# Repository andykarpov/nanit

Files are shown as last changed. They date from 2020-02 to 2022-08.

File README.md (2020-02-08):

# Alternative PCB for NANIT radiation counter.

The original article: https://radiokot.ru/circuit/digital/measure/117/

## Changes to the original schematics:

- Added factory manufactured SMD transformer instead of hand-made coil
- Added LED driver for display backlight

## PCB renders:

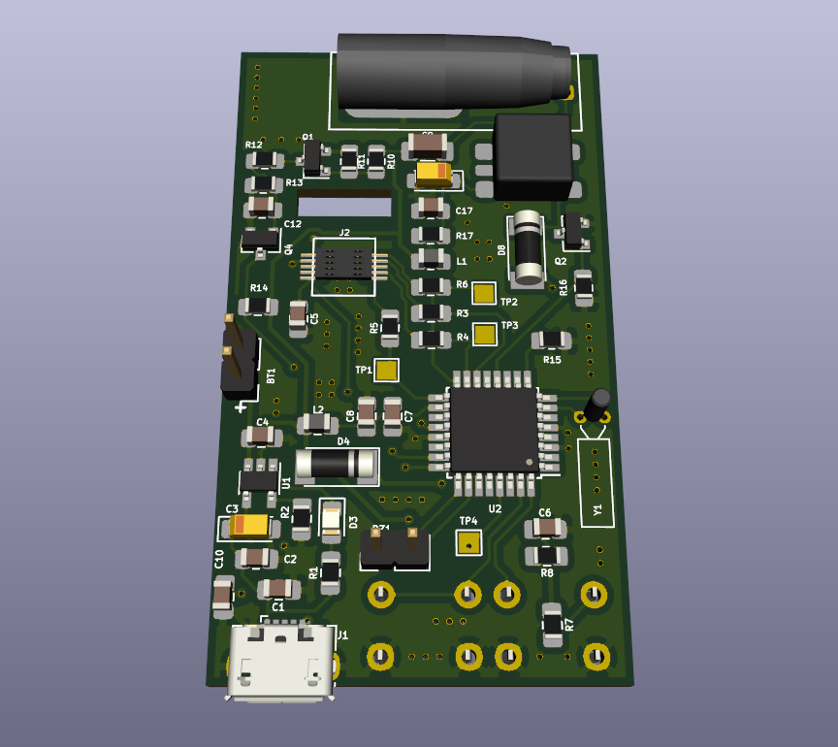
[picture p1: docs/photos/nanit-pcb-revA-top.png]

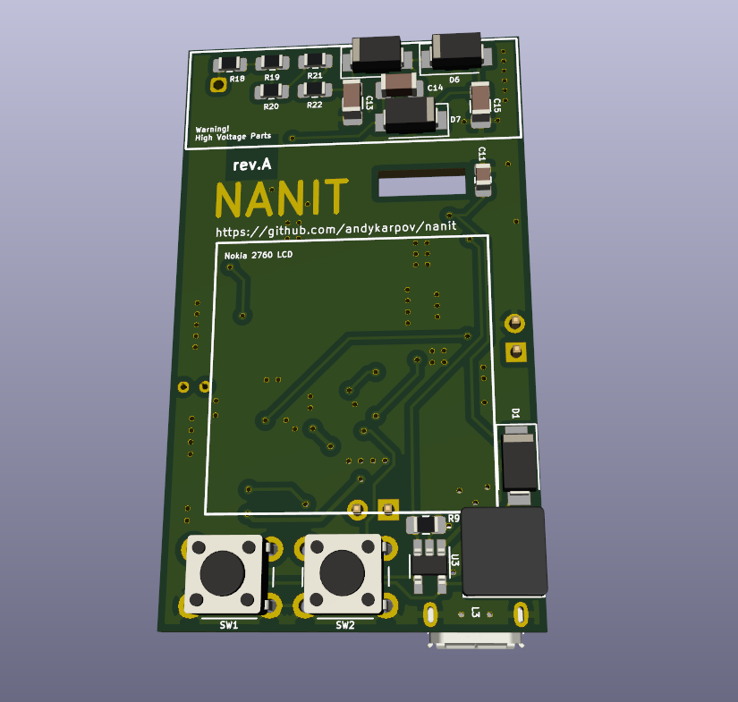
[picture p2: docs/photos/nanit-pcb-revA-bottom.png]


## OSHPark project link:

https://oshpark.com/shared_projects/OVV7hNvF

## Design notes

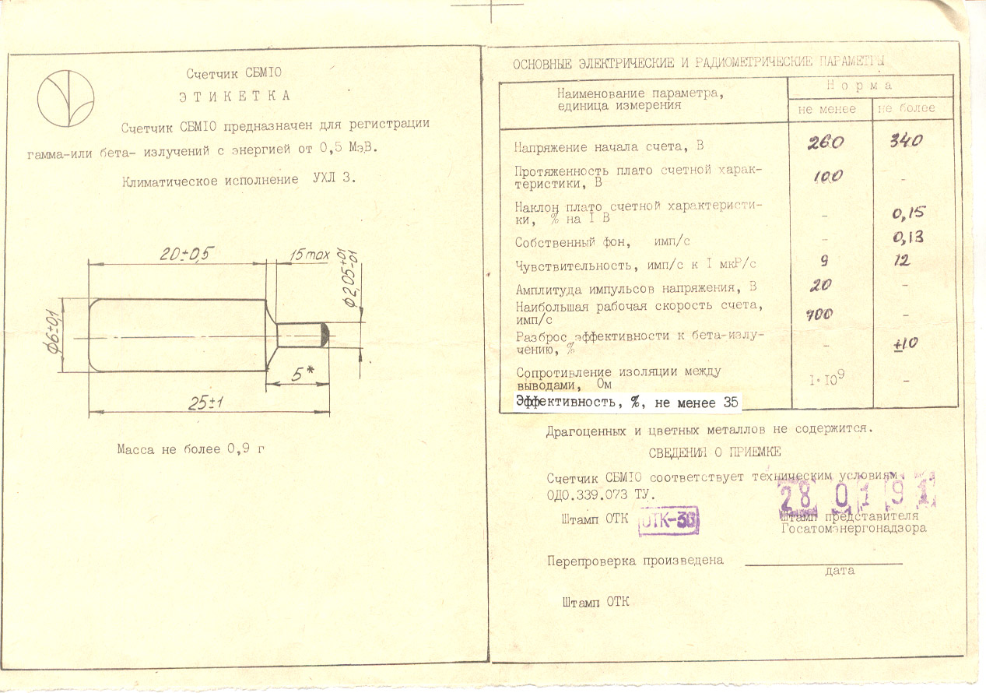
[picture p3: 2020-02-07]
docs/datasheets/sbm10.jpg

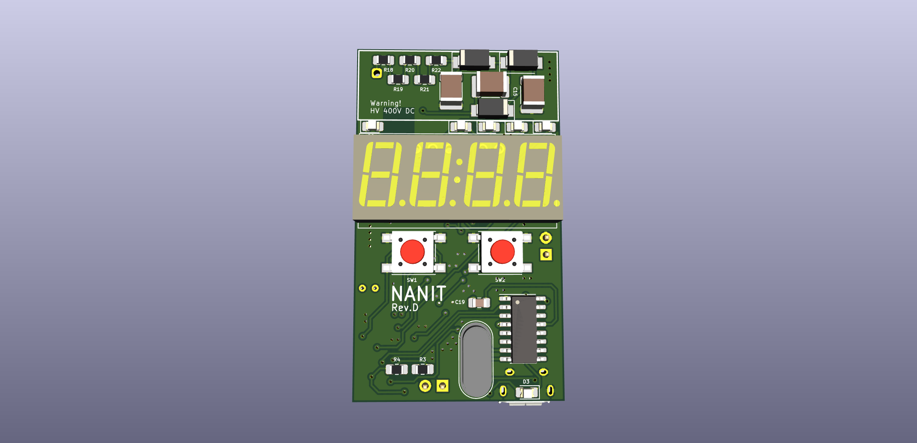
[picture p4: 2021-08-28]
docs/photos/nanit-revD-top.png

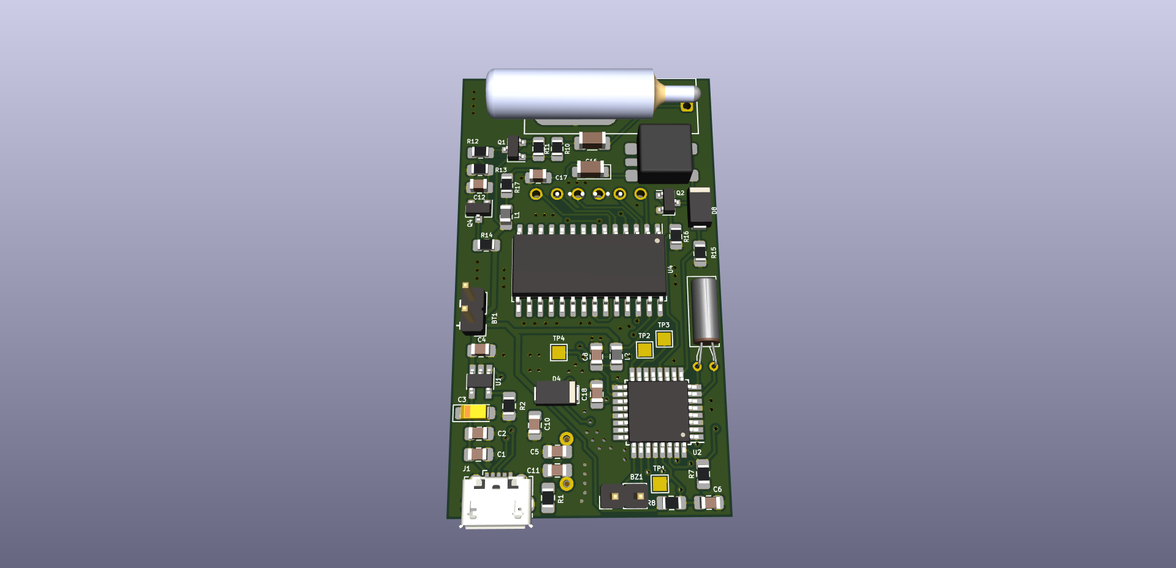
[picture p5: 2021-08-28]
docs/photos/nanit-revD-bottom.png

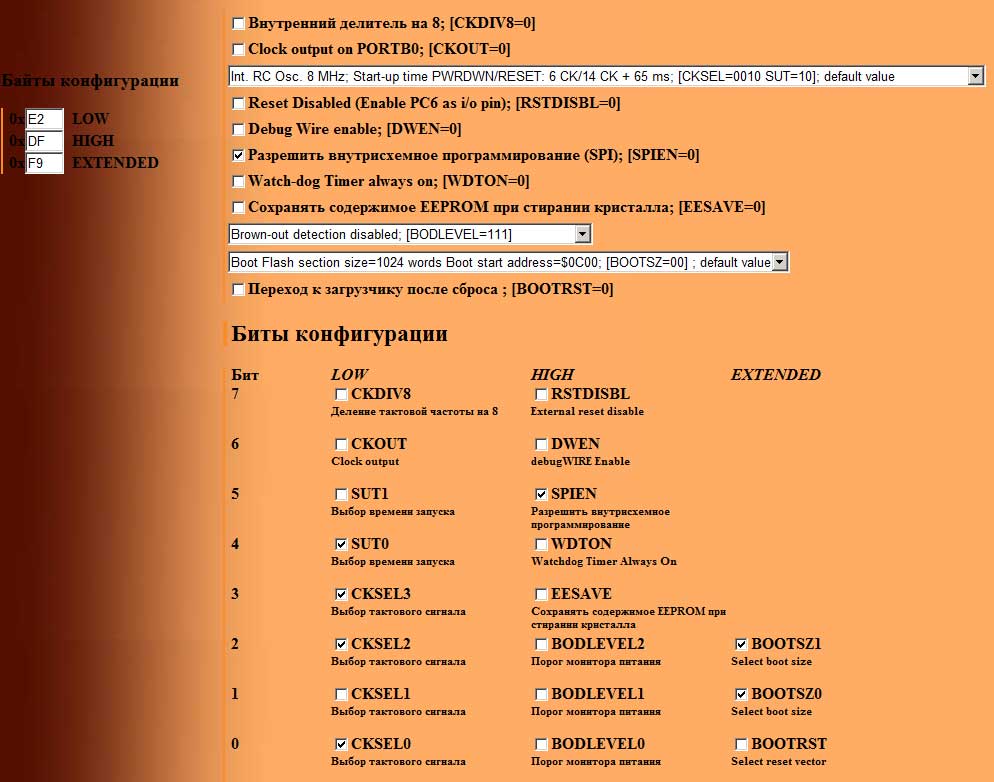
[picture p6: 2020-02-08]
firmware/sbm21/fuses.jpg

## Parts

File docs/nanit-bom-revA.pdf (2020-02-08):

### nanit-revA-bom.csv

### Page 1

Qty | Reference(s) | Value | Package | Comments
1 | BT1 | 3.7V li-ion battery | 3.7v 250mAh li-ion battery with protection
1 | BZ1 | Piezo Buzzer | 15mm piezo buzzer | voron.ua
7 | C1, C4, C5, C6, C7, C8, C17 | 100nF | 0805
2 | C2, C10 | 1uF | 0805
1 | C3 | 10uF | Tantalum A
1 | C9 | 10pF 1000V (C17UL100J-7ZN-X1T) | 1206 | voron.ua
1 | C11 | 22nF | 0805
1 | C12 | 220pF | 0805
3 | C13, C14, C15 | 100nF 600V | 1206 | voron.ua
1 | C16 | 47uF | Tantalum A
1 | D1 | SS14 | SMA
1 | D3 | LED | 0805
1 | D4 | 1N4148 | MELF
3 | D5, D6, D7 | US1M | SMA | voron.ua
1 | D8 | 18v (BZV55C18) | MELF | voron.ua
1 | J1 | USB_B_Micro | Micro USB
1 | J2 | DF23C-10DS-0.5V(51) | DF23C-10DS-0.5V(51) | https://prom.ua/p955569626-konnektor-displeya-dlya.html
2 | L1, L2 | 10uH | 0805
1 | L3 | 22uH | Coil
1 | Q1 | BC857 | SOT-23
1 | Q2 | IRLML6344 | SOT-23
1 | Q4 | BC847 | SOT-23
1 | R1 | 300R | 0805
1 | R2 | 2k* | 0805
4 | R3, R4, R5, R6 | 4k7 | 0805
6 | R7, R8, R11, R12, R13, R14 | 10k | 0805
1 | R9 | 6.34 | 0805
1 | R10 | 1k5 | 0805
1 | R15 | 750R | 0805
4 | R16, R18, R19, R20 | 1M | 0805
1 | R17 | 20R | 0805
2 | R21, R22 | 2M | 0805
1 | S1 | SBM-10 (SMB-21) | SBM-10 or SMB-21 geiger counter tube | https://www.olx.ua/obyavlenie/schetchik-sbm-10-IDGKPt7.html
2 | SW1, SW2 | Tact button | 6mm tact button

### nanit-revA-bom.csv

### Page 2

1 | TR1 | CEEH54 | CEEH54 | https://aliexpress.ru/item/32234817529.html
1 | U1 | LTC4054ES5-4.2 | SOT-23-5
1 | U2 | ATmega88PA-AU | TQFP-32 | voron.ua
1 | U3 | LT1937 | SOT-23-5 | https://aliexpress.ru/item/33025370052.html
1 | Y1 | 32.768 KHz | Crystal D2.1mm
1 | E1 | Enclosure | Sanhe 20-23-2
1 | DISP1 | Nokia 2660/2760 24x24mm display | Nokia 2660/2760 24x24mm display | https://himobile.kiev.ua/p61933946-displej-ekran-nokia.html

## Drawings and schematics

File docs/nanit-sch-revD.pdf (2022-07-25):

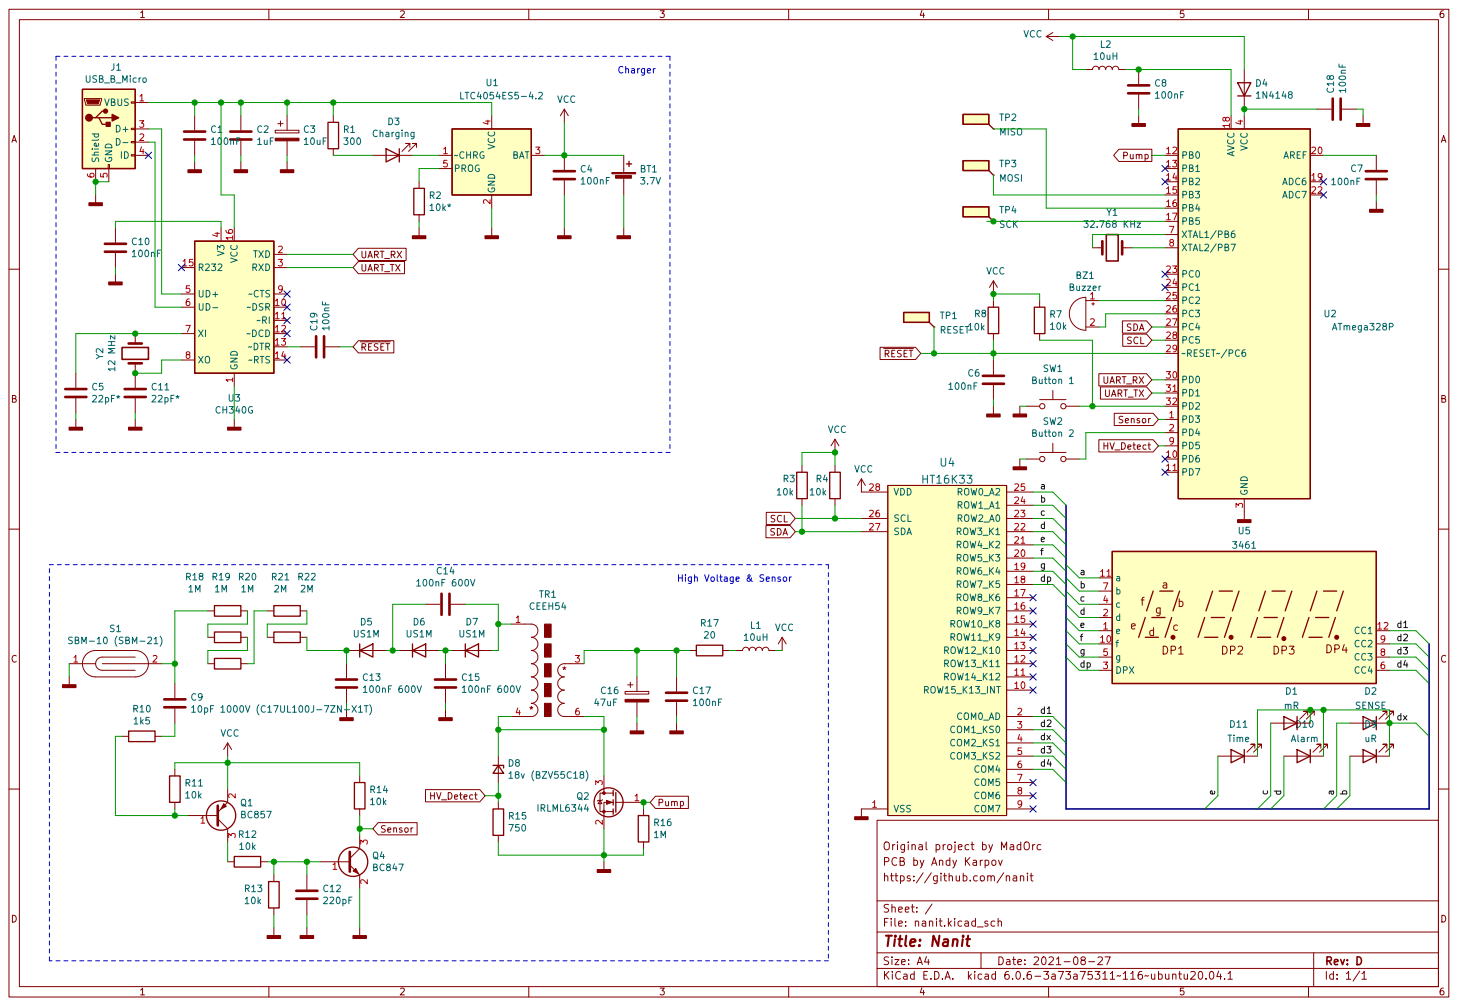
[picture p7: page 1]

4 UD+ 5 UD- 6 XI 7 XO 8 ~CTS9 U3 CH340G

fe High Voltage & Sensor

PCB by Andy Karpov
File: nanit.kicad_sch Sheet: / https://github.com/nanit

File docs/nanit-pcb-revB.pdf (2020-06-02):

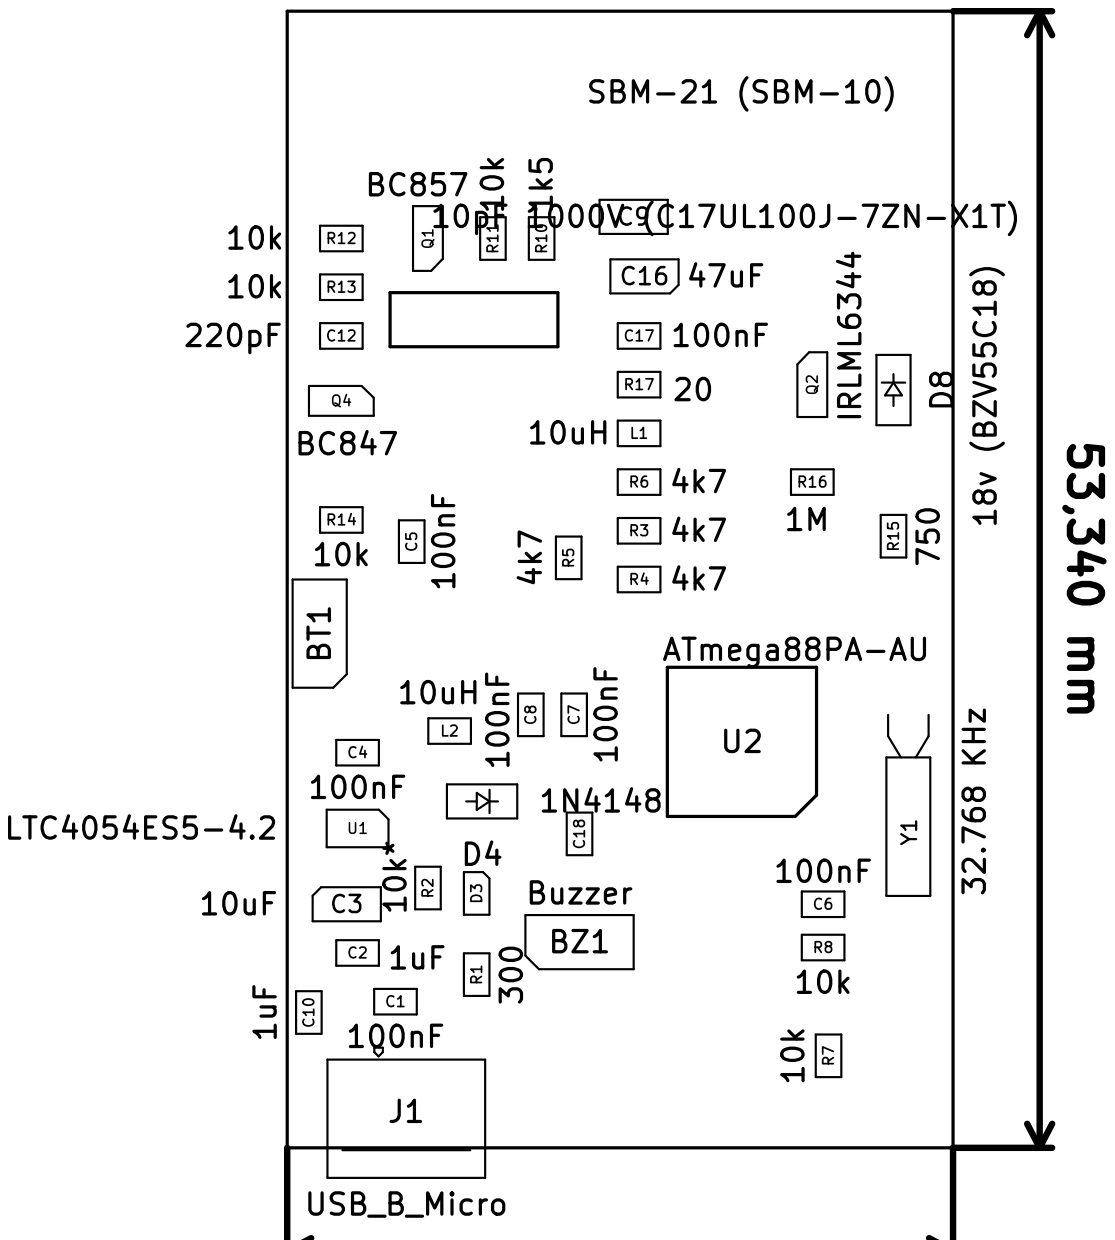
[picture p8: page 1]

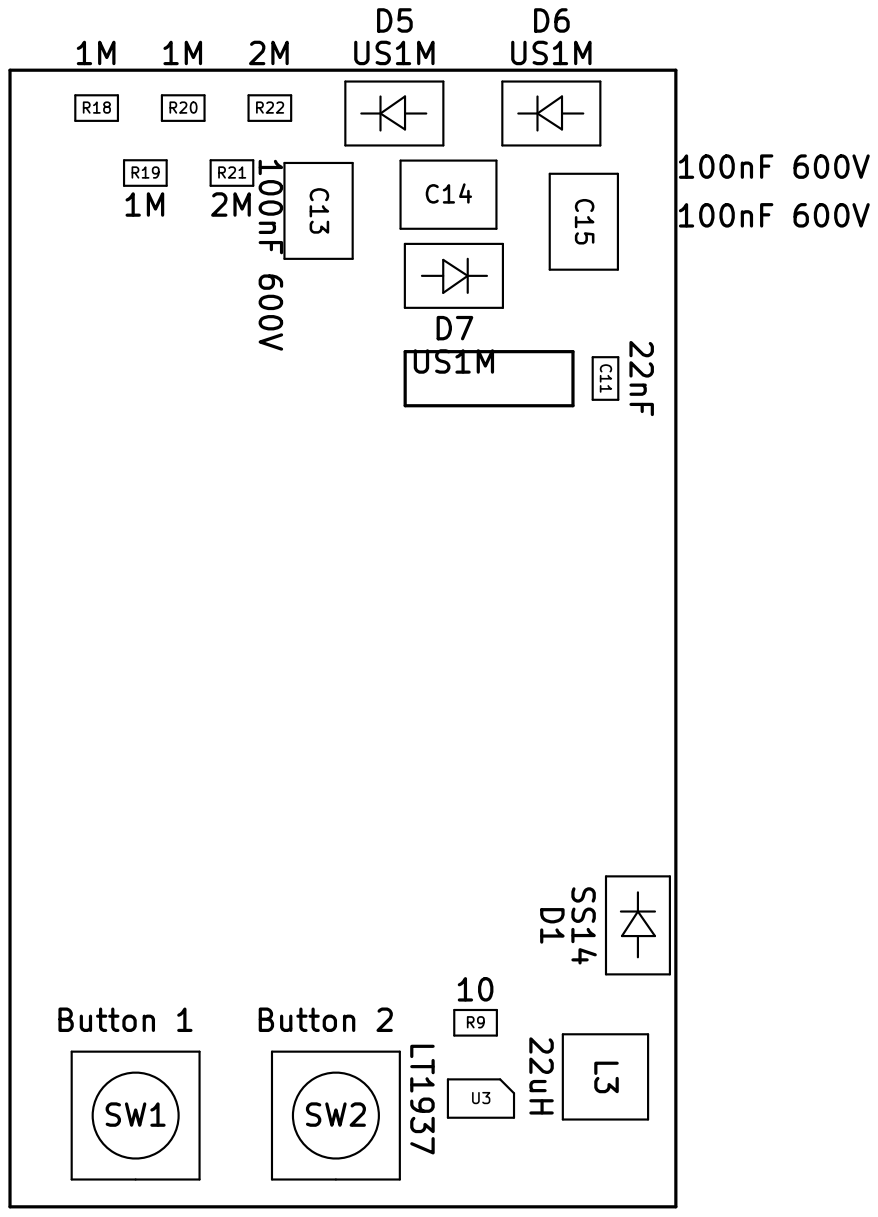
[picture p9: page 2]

### nanit-revA-bom.csv

### Page 1

Qty | Reference(s) | Value | Package | Comments
1 | BT1 | 3.7V li-ion battery | 3.7v 250mAh li-ion battery with protection
1 | BZ1 | Piezo Buzzer | 15mm piezo buzzer | voron.ua
7 | C1, C4, C5, C6, C7, C8, C17 | 100nF | 0805
2 | C2, C10 | 1uF | 0805
1 | C3 | 10uF | Tantalum A
1 | C9 | 10pF 1000V (C17UL100J-7ZN-X1T) | 1206 | voron.ua
1 | C11 | 22nF | 0805
1 | C12 | 220pF | 0805
3 | C13, C14, C15 | 100nF 600V | 1206 | voron.ua
1 | C16 | 47uF | Tantalum A
1 | D1 | SS14 | SMA
1 | D3 | LED | 0805
1 | D4 | 1N4148 | MELF
3 | D5, D6, D7 | US1M | SMA | voron.ua
1 | D8 | 18v (BZV55C18) | MELF | voron.ua
1 | J1 | USB_B_Micro | Micro USB
1 | J2 | DF23C-10DS-0.5V(51) | DF23C-10DS-0.5V(51) | https://prom.ua/p955569626-konnektor-displeya-dlya.html
2 | L1, L2 | 10uH | 0805
1 | L3 | 22uH | Coil
1 | Q1 | BC857 | SOT-23
1 | Q2 | IRLML6344 | SOT-23
1 | Q4 | BC847 | SOT-23
1 | R1 | 300R | 0805
1 | R2 | 2k* | 0805
4 | R3, R4, R5, R6 | 4k7 | 0805
6 | R7, R8, R11, R12, R13, R14 | 10k | 0805
1 | R9 | 6.34 | 0805
1 | R10 | 1k5 | 0805
1 | R15 | 750R | 0805
4 | R16, R18, R19, R20 | 1M | 0805
1 | R17 | 20R | 0805
2 | R21, R22 | 2M | 0805
1 | S1 | SBM-10 (SMB-21) | SBM-10 or SMB-21 geiger counter tube | https://www.olx.ua/obyavlenie/schetchik-sbm-10-IDGKPt7.html
2 | SW1, SW2 | Tact button | 6mm tact button

### nanit-revA-bom.csv

### Page 2

1 | TR1 | CEEH54 | CEEH54 | https://aliexpress.ru/item/32234817529.html
1 | U1 | LTC4054ES5-4.2 | SOT-23-5
1 | U2 | ATmega88PA-AU | TQFP-32 | voron.ua
1 | U3 | LT1937 | SOT-23-5 | https://aliexpress.ru/item/33025370052.html
1 | Y1 | 32.768 KHz | Crystal D2.1mm
1 | E1 | Enclosure | Sanhe 20-23-2
1 | DISP1 | Nokia 2660/2760 24x24mm display | Nokia 2660/2760 24x24mm display | https://himobile.kiev.ua/p61933946-displej-ekran-nokia.html



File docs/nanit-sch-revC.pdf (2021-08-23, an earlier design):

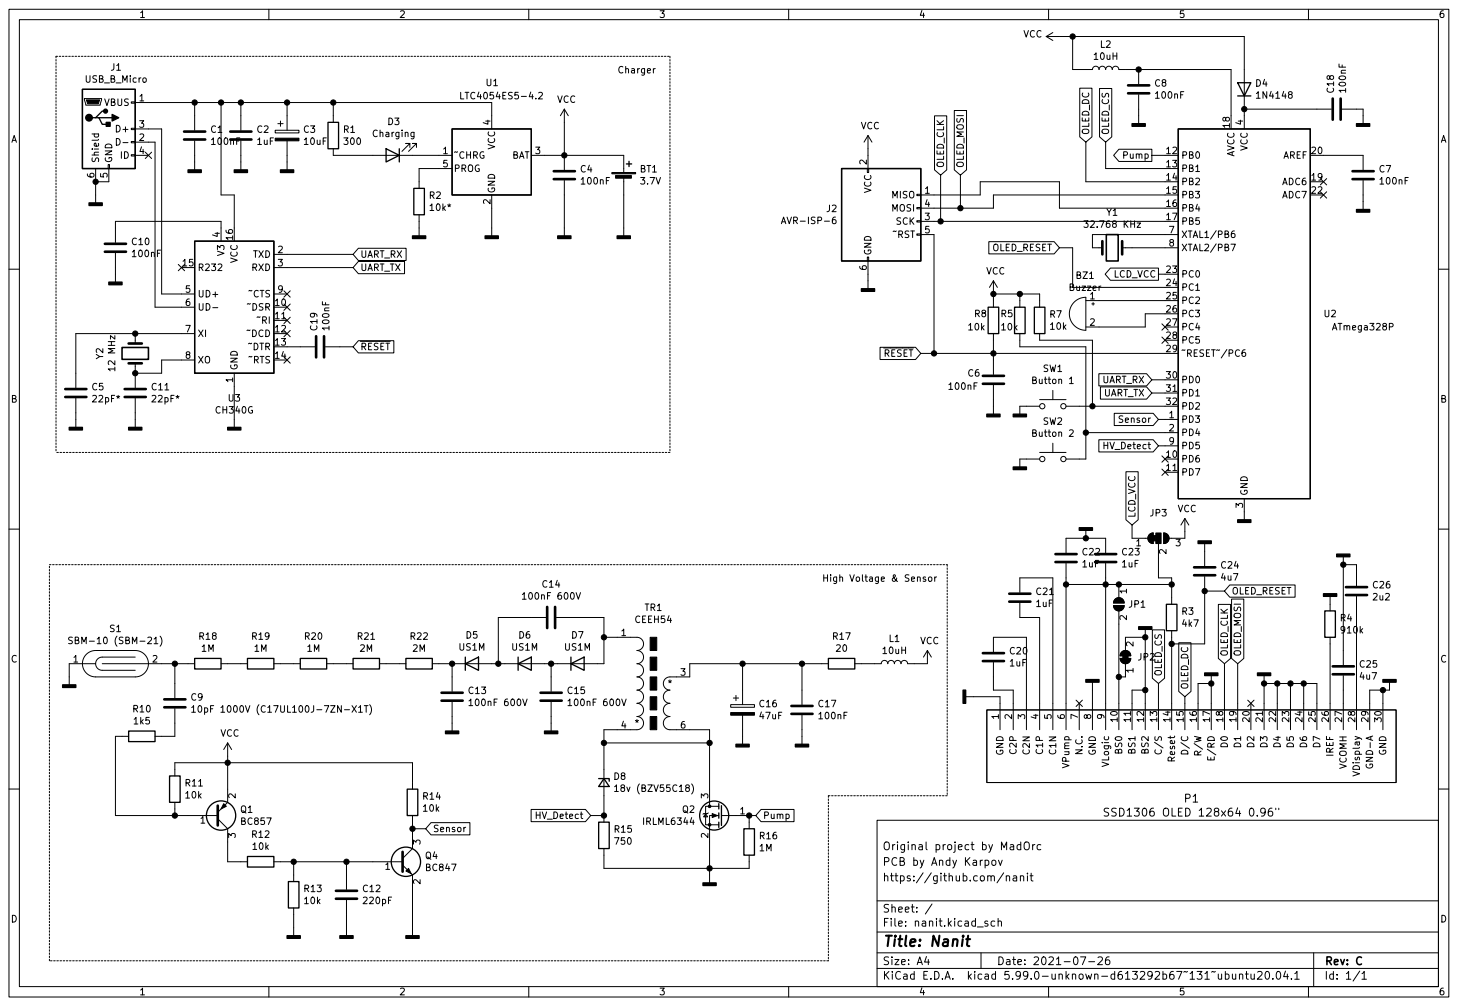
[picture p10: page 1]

2 SCK 3 MOSI 4 ~RST 5 GND

4 UD+ 5 UD- 6 XI 7 XO 8 ~CTS9 U3 CH340G C19 100nF OLED_MOSI Sensor OLED_DC

2 D2 20 D3 21 D4 22 D5 23 D6 24 D7 25 IREF 26 VCOMH 27 VDisplay 28 GND-A 29 C2N

PCB by Andy Karpov
File: nanit.kicad_sch Sheet: / https://github.com/nanit

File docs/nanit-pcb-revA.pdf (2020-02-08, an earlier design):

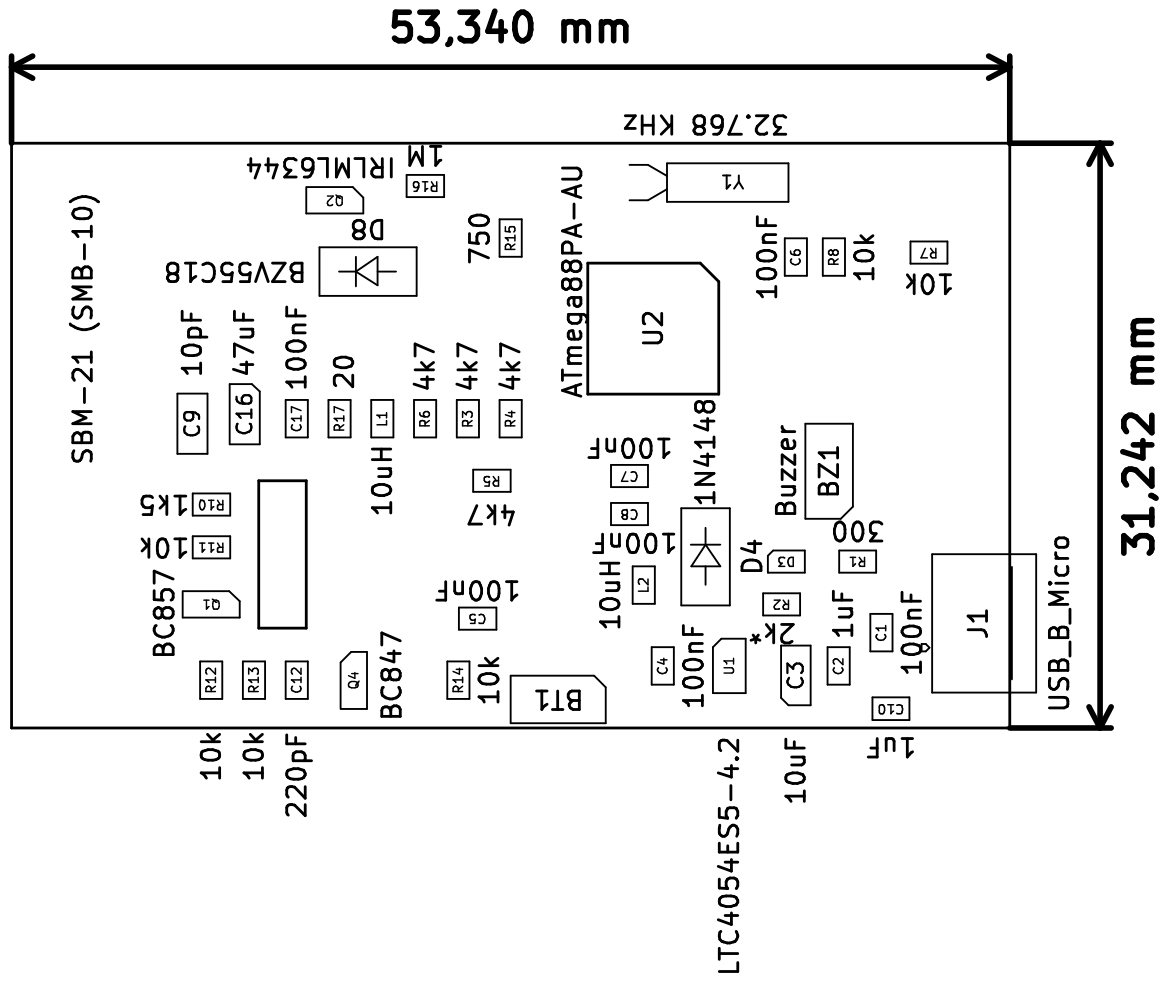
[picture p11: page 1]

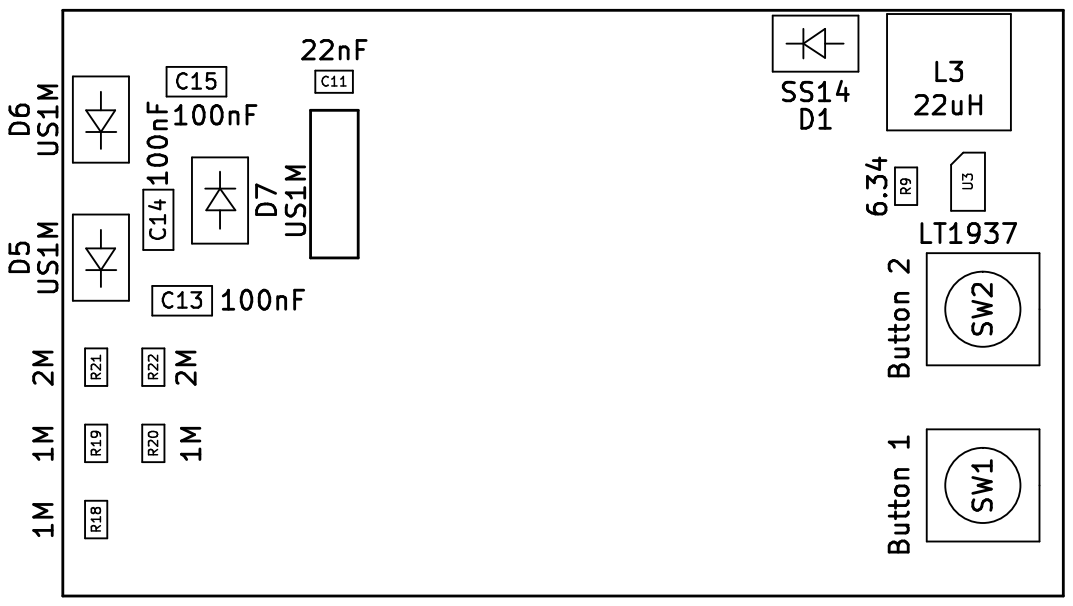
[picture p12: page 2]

### nanit-revA-bom.csv

### Page 1

Qty | Reference(s) | Value | Package | Comments
1 | BT1 | 3.7V li-ion battery | 3.7v 250mAh li-ion battery with protection
1 | BZ1 | Piezo Buzzer | 15mm piezo buzzer | voron.ua
7 | C1, C4, C5, C6, C7, C8, C17 | 100nF | 0805
2 | C2, C10 | 1uF | 0805
1 | C3 | 10uF | Tantalum A
1 | C9 | 10pF 1000V (C17UL100J-7ZN-X1T) | 1206 | voron.ua
1 | C11 | 22nF | 0805
1 | C12 | 220pF | 0805
3 | C13, C14, C15 | 100nF 600V | 1206 | voron.ua
1 | C16 | 47uF | Tantalum A
1 | D1 | SS14 | SMA
1 | D3 | LED | 0805
1 | D4 | 1N4148 | MELF
3 | D5, D6, D7 | US1M | SMA | voron.ua
1 | D8 | 18v (BZV55C18) | MELF | voron.ua
1 | J1 | USB_B_Micro | Micro USB
1 | J2 | DF23C-10DS-0.5V(51) | DF23C-10DS-0.5V(51) | https://prom.ua/p955569626-konnektor-displeya-dlya.html
2 | L1, L2 | 10uH | 0805
1 | L3 | 22uH | Coil
1 | Q1 | BC857 | SOT-23
1 | Q2 | IRLML6344 | SOT-23
1 | Q4 | BC847 | SOT-23
1 | R1 | 300R | 0805
1 | R2 | 2k* | 0805
4 | R3, R4, R5, R6 | 4k7 | 0805
6 | R7, R8, R11, R12, R13, R14 | 10k | 0805
1 | R9 | 6.34 | 0805
1 | R10 | 1k5 | 0805
1 | R15 | 750R | 0805
4 | R16, R18, R19, R20 | 1M | 0805
1 | R17 | 20R | 0805
2 | R21, R22 | 2M | 0805
1 | S1 | SBM-10 (SMB-21) | SBM-10 or SMB-21 geiger counter tube | https://www.olx.ua/obyavlenie/schetchik-sbm-10-IDGKPt7.html
2 | SW1, SW2 | Tact button | 6mm tact button

### nanit-revA-bom.csv

### Page 2

1 | TR1 | CEEH54 | CEEH54 | https://aliexpress.ru/item/32234817529.html
1 | U1 | LTC4054ES5-4.2 | SOT-23-5
1 | U2 | ATmega88PA-AU | TQFP-32 | voron.ua
1 | U3 | LT1937 | SOT-23-5 | https://aliexpress.ru/item/33025370052.html
1 | Y1 | 32.768 KHz | Crystal D2.1mm
1 | E1 | Enclosure | Sanhe 20-23-2
1 | DISP1 | Nokia 2660/2760 24x24mm display | Nokia 2660/2760 24x24mm display | https://himobile.kiev.ua/p61933946-displej-ekran-nokia.html



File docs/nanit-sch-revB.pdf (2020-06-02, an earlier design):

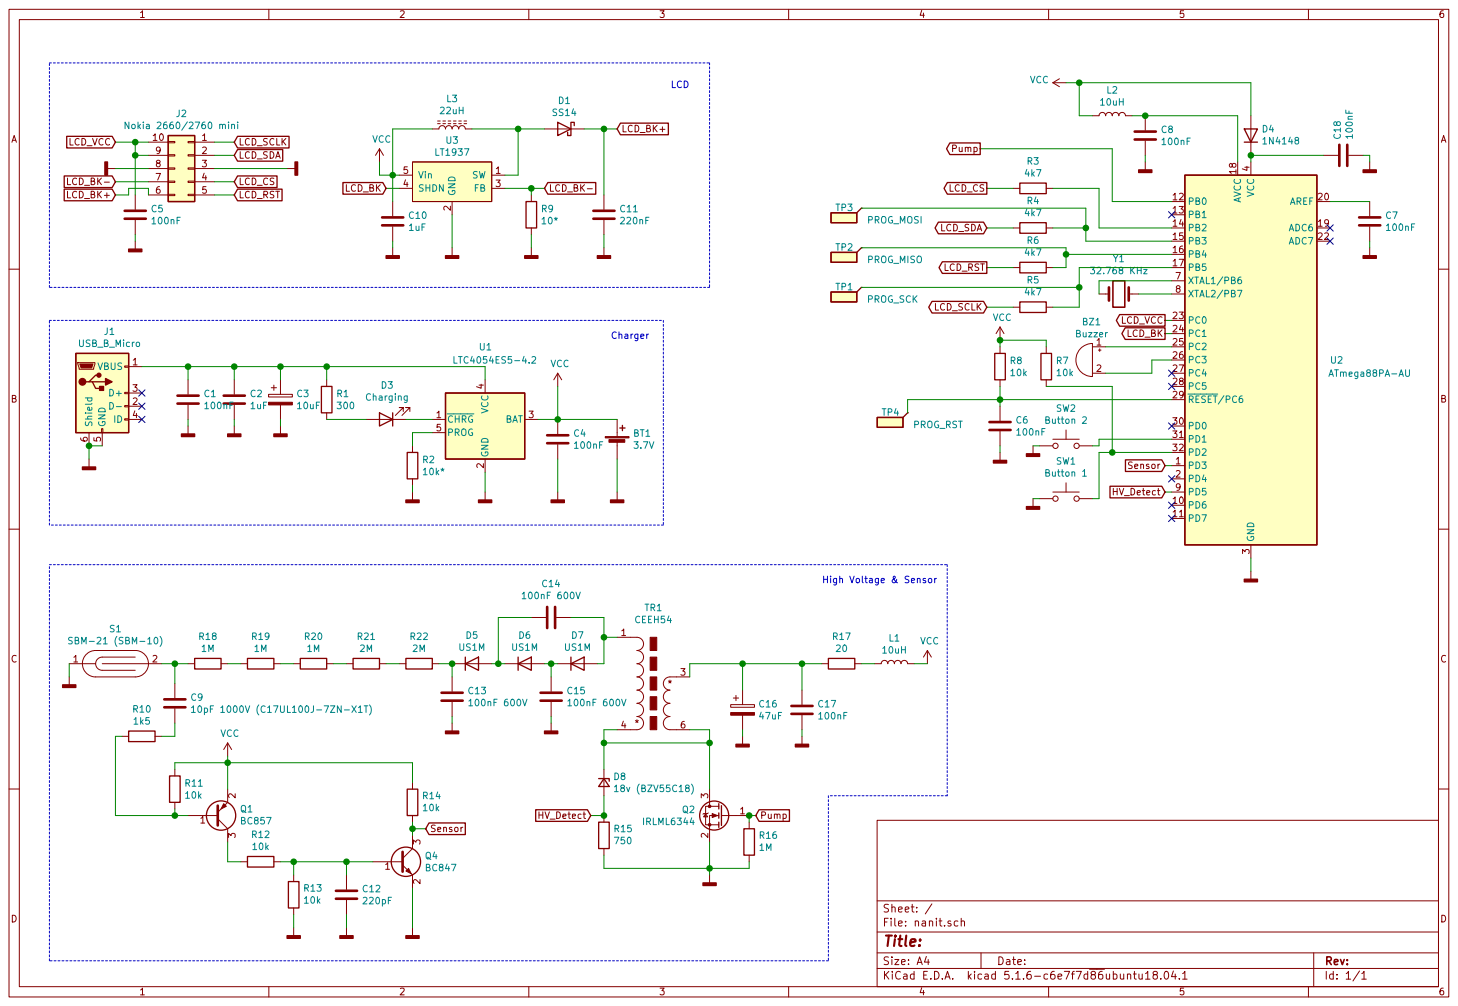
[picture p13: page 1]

Id: 1/1 Title: File: nanit.sch Sheet: /

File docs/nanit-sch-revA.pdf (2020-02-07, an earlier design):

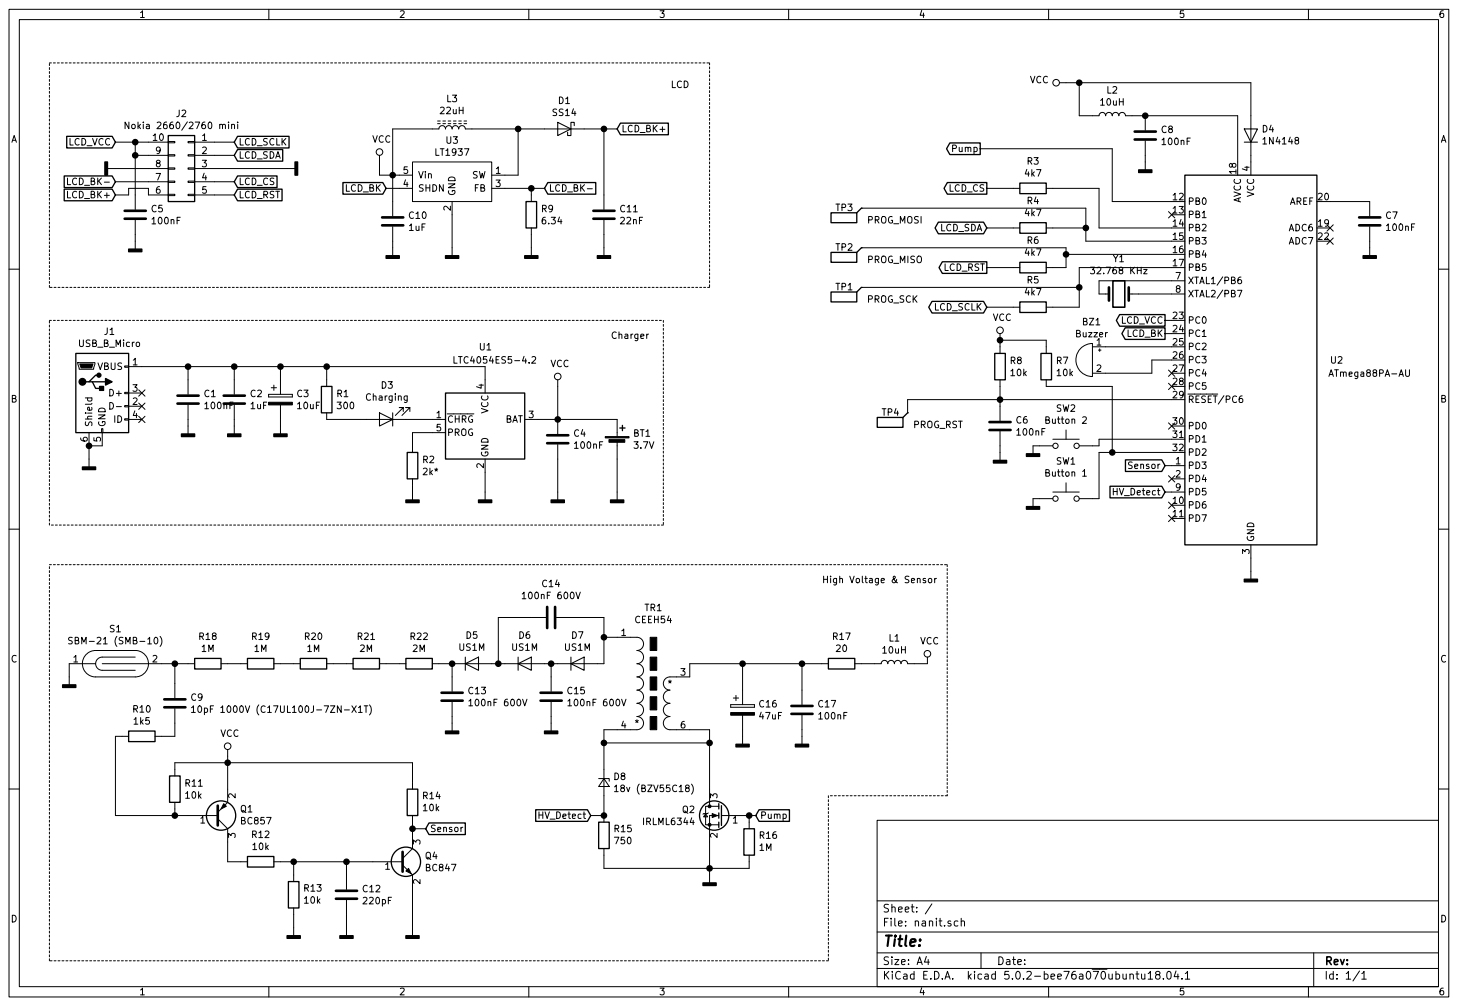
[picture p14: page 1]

Id: 1/1 Title: File: nanit.sch Sheet: /

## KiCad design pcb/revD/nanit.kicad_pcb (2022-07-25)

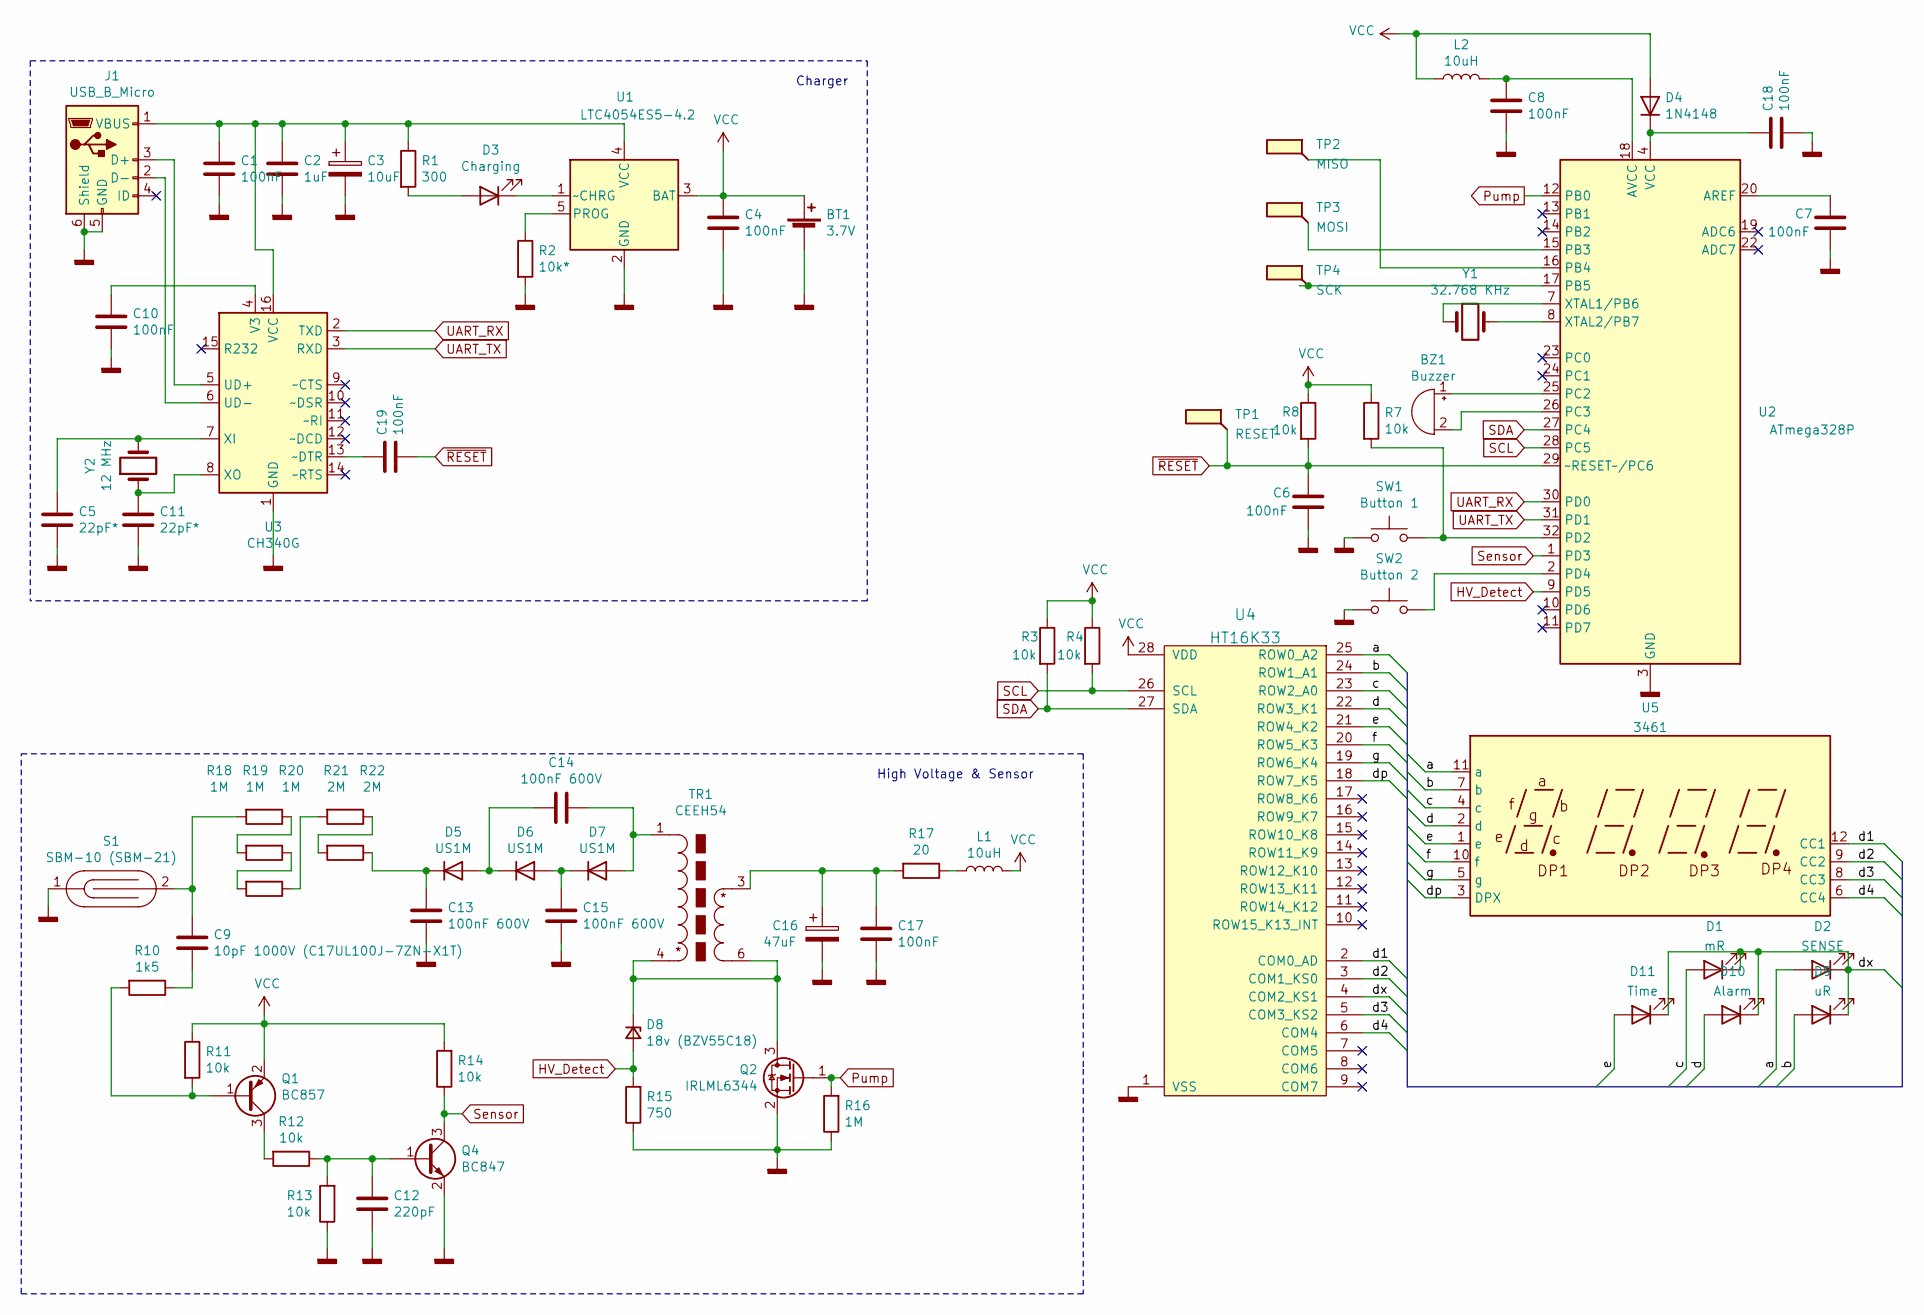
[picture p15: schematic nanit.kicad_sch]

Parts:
BT1: 3.7V; PinHeader_1x02_P2.54mm_Vertical
BZ1: Buzzer; PinHeader_1x02_P2.54mm_Vertical
C1, C4, C6, C8, C10, C17, C18, C19: 100nF; C_0805_2012Metric_Pad1.15x1.40mm_HandSolder
C2: 1uF; C_0805_2012Metric_Pad1.15x1.40mm_HandSolder
C3: 10uF; CP_EIA-3216-18_Kemet-A_Pad1.58x1.35mm_HandSolder
C5, C11: 22pF*; C_0805_2012Metric_Pad1.15x1.40mm_HandSolder
C7: 100nF; C_0805_2012Metric_Pad1.18x1.45mm_HandSolder
C9: 10pF 1000V (C17UL100J-7ZN-X1T); C_1206_3216Metric_Pad1.42x1.75mm_HandSolder
C12: 220pF; C_0805_2012Metric_Pad1.15x1.40mm_HandSolder
C13, C14, C15: 100nF 600V; C_1812_4532Metric_Pad1.30x3.40mm_HandSolder
C16: 47uF; CP_EIA-3216-18_Kemet-A_Pad1.58x1.35mm_HandSolder
D1: mR; LED_0805_2012Metric_Pad1.15x1.40mm_HandSolder
D2: SENSE; LED_0805_2012Metric_Pad1.15x1.40mm_HandSolder
D3: Charging; LED_0805_2012Metric_Pad1.15x1.40mm_HandSolder
D4: 1N4148; D_MiniMELF
D5, D6, D7: US1M; D_SMA
D8: 18v (BZV55C18); D_MiniMELF
D9: uR; LED_0805_2012Metric_Pad1.15x1.40mm_HandSolder
D10: Alarm; LED_0805_2012Metric_Pad1.15x1.40mm_HandSolder
D11: Time; LED_0805_2012Metric_Pad1.15x1.40mm_HandSolder
J1: USB_B_Micro; USB_Micro-B_Amphenol_10118194_Horizontal
L1, L2: 10uH; L_0805_2012Metric_Pad1.15x1.40mm_HandSolder
Q1: BC857; SOT-23
Q2: IRLML6344; SOT-23
Q4: BC847; SOT-23
R1: 300; R_0805_2012Metric_Pad1.15x1.40mm_HandSolder
R2: 10k*; R_0805_2012Metric_Pad1.15x1.40mm_HandSolder
R3, R4: 10k; R_0805_2012Metric_Pad1.20x1.40mm_HandSolder
R7, R8, R11, R12, R13, R14: 10k; R_0805_2012Metric_Pad1.15x1.40mm_HandSolder
R10: 1k5; R_0805_2012Metric_Pad1.15x1.40mm_HandSolder
R15: 750; R_0805_2012Metric_Pad1.15x1.40mm_HandSolder
R16, R18, R19, R20: 1M; R_0805_2012Metric_Pad1.15x1.40mm_HandSolder
R17: 20; R_0805_2012Metric_Pad1.15x1.40mm_HandSolder
R21, R22: 2M; R_0805_2012Metric_Pad1.15x1.40mm_HandSolder
S1: SBM-10 (SBM-21); SBM-21
SW1: Button 1; SW_Push_1P1T_NO_6x6mm_H9.5mm
SW2: Button 2; SW_Push_1P1T_NO_6x6mm_H9.5mm
TP1: RESET; TestPoint_Pad_1.5x1.5mm
TP2: MISO; TestPoint_Pad_1.5x1.5mm
TP3: MOSI; TestPoint_Pad_1.5x1.5mm
TP4: SCK; TestPoint_Pad_1.5x1.5mm
TR1: CEEH54
U1: LTC4054ES5-4.2; TSOT-23-5
U2: ATmega328P; TQFP-32_7x7mm_P0.8mm
U3: CH340G; SOIC-16_3.9x9.9mm_P1.27mm
U4: HT16K33; SOIC-28W_7.5x17.9mm_P1.27mm
U5: 3461; 7SEG-3461
Y1: 32.768 KHz; Crystal_C38-LF_D3.0mm_L8.0mm_Horizontal
Y2: 12 MHz; Crystal_HC49-U_Vertical

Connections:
/a: D2.2 (A), U4.25 (ROW0_A2), U5.11 (a)
/b: D9.2 (A), U4.24 (ROW1_A1), U5.7 (b)
/c: D1.2 (A), U4.23 (ROW2_A0), U5.4 (c)
/d: D10.2 (A), U4.22 (ROW3_K1), U5.2 (d)
/d1: U4.2 (COM0_AD), U5.12 (CC1)
/d2: U4.3 (COM1_KS0), U5.9 (CC2)
/d3: U4.5 (COM3_KS2), U5.8 (CC3)
/d4: U4.6 (COM4), U5.6 (CC4)
/dp: U4.18 (ROW7_K5), U5.3 (DPX)
/dx: D1.1 (K), D2.1 (K), D9.1 (K), D10.1 (K), D11.1 (K), U4.4 (COM2_KS1)
/e: D11.2 (A), U4.21 (ROW4_K2), U5.1 (e)
/f: U4.20 (ROW5_K3), U5.10 (f)
/g: U4.19 (ROW6_K4), U5.5 (g)
GNDD: BT1.2 (-), C1.2, C2.2, C3.2, C4.2, C5.2, C6.2, C7.2, C8.2, C10.2, C11.2, C12.2, C13.2, C15.2, C16.2, C17.2, C18.2, J1.5 (GND), J1.6 (Shield), Q2.2 (S), Q4.2 (E), R2.2, R13.1, R15.1, R16.1, S1.1, SW1.1, SW2.1, U1.2 (GND), U2.3 (GND), U2.5 (GND), U2.21 (GND), U3.1 (GND), U4.1 (VSS)
HV_Detect: D8.2 (A), R15.2, U2.9 (PD5)
unnamed: BZ1.1 (-), U2.25 (PC2)
unnamed: BZ1.2 (+), U2.26 (PC3)
unnamed: C1.1, C2.1, C3.1, J1.1 (VBUS), R1.1, U1.4 (VCC), U3.16 (VCC)
unnamed: C5.1, U3.7 (XI), Y2.2
unnamed: C8.1, L2.2, U2.18 (AVCC)
unnamed: C9.1, R18.2, S1.2
unnamed: C9.2, R10.1
unnamed: C10.1, U3.4 (V3)
unnamed: C11.1, U3.8 (XO), Y2.1
unnamed: C12.1, Q4.1 (B), R12.1, R13.2
unnamed: C13.1, D5.1 (K), R22.1
unnamed: C14.1, D5.2 (A), D6.1 (K)
unnamed: C14.2, D7.2 (A), TR1.1
unnamed: C15.1, D6.2 (A), D7.1 (K)
unnamed: C16.1, C17.1, R17.2, TR1.3
unnamed: C18.1, D4.1 (K), U2.4 (VCC), U2.6 (VCC)
unnamed: C19.1, U3.13 (~DTR)
unnamed: D3.1 (K), U1.1 (~CHRG)
unnamed: D3.2 (A), R1.2
unnamed: D8.1 (K), Q2.3 (D), TR1.4, TR1.6
unnamed: J1.2 (D-), U3.6 (UD-)
unnamed: J1.3 (D+), U3.5 (UD+)
unnamed: L1.1, R17.1
unnamed: Q1.1 (B), R10.2, R11.2
unnamed: Q1.3 (C), R12.2
unnamed: R2.1, U1.5 (PROG)
unnamed: R7.2, SW1.2, U2.32 (PD2)
unnamed: R18.1, R19.2
unnamed: R19.1, R20.2
unnamed: R20.1, R21.2
unnamed: R21.1, R22.2
unnamed: SW2.2, U2.2 (PD4)
unnamed: TP2.1, U2.16 (PB4)
unnamed: TP3.1, U2.15 (PB3)
unnamed: TP4.1, U2.17 (PB5)
unnamed: U2.7 (XTAL1/PB6), Y1.1
unnamed: U2.8 (XTAL2/PB7), Y1.2
unnamed: C7.1, U2.20 (AREF)
Pump: Q2.1 (G), R16.2, U2.12 (PB0)
SCL: R4.2, U2.28 (PC5), U4.26 (SCL)
SDA: R3.2, U2.27 (PC4), U4.27 (SDA)
Sensor: Q4.3 (C), R14.1, U2.1 (PD3)
UART_RX: U2.30 (PD0), U3.2 (TXD)
UART_TX: U2.31 (PD1), U3.3 (RXD)
VCC: BT1.1 (+), C4.1, D4.2 (A), L1.2, L2.1, Q1.2 (E), R3.1, R4.1, R7.1, R8.1, R11.1, R14.2, U1.3 (BAT), U4.28 (VDD)
~RESET: C6.1, C19.2, R8.2, TP1.1, U2.29 (~RESET~/PC6)

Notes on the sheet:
Charger
High Voltage & Sensor

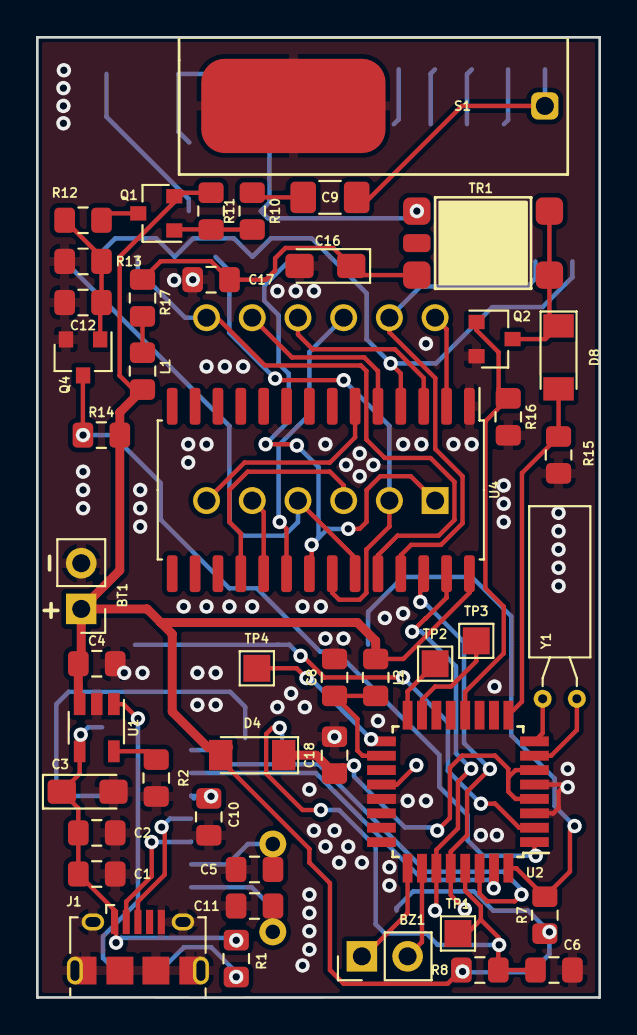
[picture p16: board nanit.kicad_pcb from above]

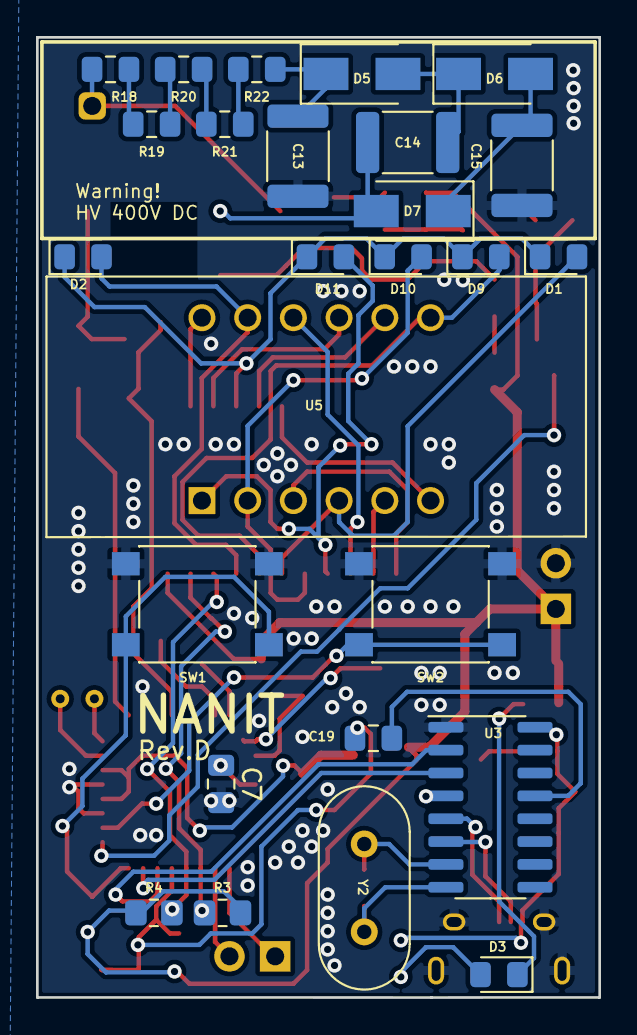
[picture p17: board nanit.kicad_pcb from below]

Board: 2 copper layers, 31.2 x 53.3 mm, 72 parts (26 on the bottom side), 61 nets.

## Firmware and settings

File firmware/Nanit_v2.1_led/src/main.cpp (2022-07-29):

/**
 * Nanit v3.0
 * 
 * Custom firmware for 4-digit LED + ht16k33 driver
 * 
 * @author MadOrd
 * @author andykarpov
 */

#include <Arduino.h>
#include <EEPROM.h>
#include "SevenSegment.h"
//#include <SoftwareSerial.h>
#include "config.h"

SevenSegment matrix = SevenSegment();

//SoftwareSerial mySerial(0, 1); 

#define	BEEP_1		PORTC |= (1<<PORTC2);	PORTC &= ~(1<<PORTC3)
#define	BEEP_2		PORTC &= ~(1<<PORTC2);	PORTC |= (1<<PORTC3)
#define	BEEP_OFF	PORTC &= ~ (1<<PORTC2);	PORTC &= ~ (1<<PORTC3)

const uint8_t alarm_snooze_time = 5; // время в минутах, сколько не выводить ни один тип тревоги после нажатия на кнопку

#if BATTERY_TYPE == BATTERY_LION
	const uint16_t batt_warn = 320;	 // порог сообщения "Зарядите батарею" для литиевого аккума min=320
#else
	const uint16_t batt_warn = 245;	 // порог сообщения "Замените батарейки" min=245
#endif

const uint32_t pow10Table32[]=
{
	100000ul,
	10000ul,
	1000ul,
	100ul,
	10ul,
	1ul
};

volatile uint8_t hv_status, batt=0, count_flag=0;
char txt[7];
uint8_t awaken = 30, go_to_bed = 0, out_of_bed = 0, alarm_snooze = 0, alarm_beep = 0, fonerr = 0;
uint8_t go_shutdown = 0, do_shutdown = 0, recount = 0;  
uint8_t second = 0, minute = 0, hour = 12, battery_percent, lcd_redraw = 0, blink_status = 0, piip = 0;
volatile uint16_t pumpbreak;
uint8_t rad_counted = 0, idle_pump = 0;

#if (SENSOR_TYPE == SENSOR_SBM21)
	uint16_t sbm[142]; //массив импульсов
	uint16_t sbm_count_time=420, count_validate=420;
#elif (SENSOR_TYPE == SENSOR_SBM21_2)
	uint16_t sbm[110]; //массив импульсов
	uint16_t sbm_count_time=216, count_validate=216;
#elif (SENSOR_TYPE == SENSOR_SI19)
	uint16_t sbm[50]; //массив импульсов
	uint16_t sbm_count_time=64, count_validate=64;
#elif (SENSOR_TYPE == SENSOR_SBM20)
	uint16_t sbm[50]; //массив импульсов
	uint16_t sbm_count_time=44, count_validate=44;
#elif (SENSOR_TYPE == SENSOR_SBM10)
	uint16_t sbm[112]; //массив импульсов
	uint16_t sbm_count_time=220, count_validate=220;
#elif (SENSOR_TYPE == SENSOR_M_SEL)
	uint16_t sbm[142]; //массив импульсов
	uint16_t sbm_count_time, count_validate;
#else
	#error *** Не определен тип датчика/GM tube type not defined ***
#endif

unsigned long fon = 0, rad = 0;
unsigned long fon_daily = 0, fonall = 0, fonsecond = 0, div_graph_sbm = 1, radmax = 0;
unsigned int beep_counter = 0, beep_length, days = 0;
volatile unsigned int VL = 0;
unsigned int VoltLevel = 0;

uint8_t sleep_level, beep_level, brightness_level, ion, impulse;
uint8_t counter = 0;
unsigned int alarm_level;

enum screen_state_e {
	state_main = 0,
	state_menu,
	state_settings,
	state_alarm,
	state_low_battery,
	state_error,
	state_boot
};
screen_state_e scr = state_main;

enum button_state_e {
	state_key_1 = 1,
	state_key_2,
	state_key_none
};
button_state_e key = state_key_none;

enum menu_state_e {
	state_menu_alarm = 1,
	state_menu_sleep,
	state_menu_impulse,
	state_menu_brightness,
	state_menu_settings,
	state_menu_reset_doze,
	state_menu_power_off
};
menu_state_e menu = state_menu_alarm;

enum settings_state_e {
	state_settings_hours = 1,
	state_settings_minutes,
	state_settings_ion,
	state_settings_pump,
	state_settings_sensor
};
settings_state_e settings = state_settings_hours;

enum main_state_e {
	state_main_current = 0,
	state_main_time,
	state_main_battery
};

main_state_e displaying_dose = state_main_current;

void beep(unsigned char tone, unsigned char duration);
static void pump();
void lcd_clear();
void pins_on();
void pins_off();

//////////////////////////////////////////////////////////////////////////
void(* resetMC) (void) = 0; // Reset MC

//////////////////////////////////////////////////////////////////////////
EMPTY_INTERRUPT (ADC_vect)

//////////////////////////////////////////////////////////////////////////
ISR(INT0_vect) // Кнопка1
{
	SMCR &=~ (1 << SE); // сны запрещены
	if (do_shutdown)
	{
		do_shutdown = 0;
		resetMC();
	}

	if (sleep_level) awaken = sleep_level+1; else awaken = 61;
	scr = state_main; // Если уснули в меню - проснемся на главном
	out_of_bed = 1;
	piip = 0;
	beep(BEEP_TONE_ALARM, 20);
	displaying_dose = state_main_current;
	key = state_key_none; // пустая обработка, чтобы при выходе из сна, не реагировал на кнопку
}

//////////////////////////////////////////////////////////////////////////
ISR(INT1_vect) // импульсы с датчика 0
{
	PORTB &= ~(1<<PORTB0); //на всякий...
	sbm[0]++;
	piip = 1;
}

//////////////////////////////////////////////////////////////////////////
ISR(TIMER2_OVF_vect)	// обработчик прерывания по совпадению Т2
{                       
	PORTB &= ~(1<<PORTB0);	//на всякий...

	TCNT2 = 0xE0;			//обновим счетчик

	second++;				// увеличиваем секунды

	if (awaken ==1 ) go_to_bed = 1; // СПАТЬ!
	
	if ((awaken) && (sleep_level)) awaken--; //обратный отсчёт до сна

	if (count_validate>0) count_validate--;

	#if (SENSOR_TYPE == SENSOR_SBM21)	// 3!! секунды
		if (!count_flag)	// 0
		{
			div_graph_sbm = 1;
			for(uint8_t i = 139; i>0; i--) // k - не менее отображаемого графа [48]/[96]!
			{
				sbm[i] = sbm[i-1];
				if ((sbm[i] > div_graph_sbm) && (i < 96)) div_graph_sbm = sbm[i]; // Делитель графиков.
			}
			sbm[0] = 0;
		}
		if (count_flag<2) count_flag++; else count_flag = 0;

	#elif (SENSOR_TYPE == SENSOR_SBM21_2) // 2!! секунды
		if (count_flag)
		{
			div_graph_sbm = 1;
			for(uint8_t i = 107; i>0; i--) // k - не менее отображаемого графа [48]/[96]!
			{
				sbm[i] = sbm[i-1];
                if ((sbm[i] > div_graph_sbm) && (i < 96)) div_graph_sbm = sbm[i]; // Делитель графиков.
			}
			sbm[0] = 0;
		}
		if (count_flag) count_flag = 0; else count_flag = 1;

	#elif (SENSOR_TYPE == SENSOR_SI19) // 2 секунды
		if (count_flag)
		{
			div_graph_sbm = 1;
			for(uint8_t i=50; i>0; i--) // k - не менее отображаемого графа [48]!
			{
				sbm[i] = sbm[i-1];
				if ((sbm[i] > div_graph_sbm) && (i < 48)) div_graph_sbm = sbm[i]; // Делитель графиков.
			}
			sbm[0] = 0;
		}
		if (count_flag) count_flag = 0; else count_flag = 1;

	#elif (SENSOR_TYPE == SENSOR_SBM10)   // 2 секунды
		if (count_flag)
		{
			div_graph_sbm = 1;
			for(uint8_t i = 109; i>0; i--) // k - не менее отображаемого графа [48]/[96]!
			{
				sbm[i] = sbm[i-1];
                if ((sbm[i] > div_graph_sbm) && (i<96)) div_graph_sbm = sbm[i]; // Делитель графиков.
			}
			sbm[0] = 0;
		}
		if (count_flag) count_flag = 0; else count_flag = 1;

	#elif (SENSOR_TYPE == SENSOR_SBM20) // 1!!! секунда
		div_graph_sbm = 1;
		for(uint8_t i=50; i>0; i--) // k - не менее отображаемого графа [48]!
		{
			sbm[i] = sbm[i-1];
			if ((sbm[i] > div_graph_sbm) && (i < 48)) div_graph_sbm = sbm[i]; // Делитель графиков.
		}
		sbm[0] = 0;

	#elif (SENSOR_TYPE == SENSOR_M_SEL)
		if (counter == SENSOR_SBM10)
		{
			if (count_flag<1) count_flag++; else count_flag=0;
		}
		else
		{
			if (count_flag<2) count_flag++; else count_flag=0;
		}
		if (!count_flag)
		{
			div_graph_sbm = 1;
			uint8_t m;
			if (counter == SENSOR_SBM10) m=109;
			else m=139;
			
            for(uint8_t i=m; i>0; i--) // k - не менее отображаемого графа [48]!
			{
				sbm[i] = sbm[i-1];
				if ((sbm[i] > div_graph_sbm) && (i < 96)) div_graph_sbm = sbm[i]; // Делитель графиков.
			}
		sbm[0] = 0;
		}
	#else
	#error *** Не определен тип датчика/GM tube type not defined ***
	#endif

	//if ((rad>radmax)&&(!count_validate)) radmax=rad; // Валидно - если измерено.
    if (rad > radmax) radmax = rad; // Забиваем на валидность
	fonsecond += rad; // 
	fon_daily = (fon_daily + fonsecond)/3600;
	if(second == 60)			// если second = 60, second = 0
	{  // second
		second = 0;
		minute++;				// увеличиваем минуты
		if (alarm_snooze) alarm_snooze--;
		if (!rad) fonerr++;
		if ((fonerr > 10) && (!alarm_snooze)) { lcd_clear(); scr = state_error; alarm_beep = 2; fonerr = 0;} // Ошибка датчика, нет импульсов 
		batt = 1;

		if(minute == 60)		// если minute = 60, minute = 0
		{  // minute
			minute = 0;
			hour++;				// увеличиваем часы

		if(hour == 24)			// если hour = 24, hour = 0
		{ // hour
			hour = 0;
			days++;
			fonall += fon_daily;
			fonsecond = 0;
			fon_daily = 0;
			radmax = 0;

		} // hour
		} // minute
		} // second

	if (second %2 == 0) pump();
	lcd_redraw = 1;
	recount = 1;
}

//////////////////////////////////////////////////////////////////////////
ISR(TIMER0_COMPA_vect)
{ //sound
	if (blink_status) 
	{
		BEEP_1;
		blink_status = 0;
	}
	else
	{
		BEEP_2;
		blink_status = 1;
	}

	if (beep_counter++ > beep_length)	// 
	{ 
		TIMSK0 &=~ (1 << OCIE0A); 
		BEEP_OFF;
		beep_counter = 0; 
		if (alarm_beep == 2)	{alarm_beep = 0; beep(BEEP_TONE_KEY1, 254);}
	}
}

void lcd_clear()
{
	matrix.clear();
}

//Инициализация дисплея
void lcd_init()
{
	matrix.begin(0x70);
	matrix.setBrightness(brightness_level);
}

void beep(unsigned char tone, unsigned char duration)
{
	if (beep_counter) return;
	//beep_length = duration * 10;
	//OCR0A = tone;
	beep_length = duration;
	OCR0A = tone;
	TIMSK0 |= (1 << OCIE0A);
}

static void pump()
{
	unsigned int pumpa;

	if (impulse > 11) impulse = 11;
	if (impulse < 1) impulse = 1;

	pumpbreak = 0;
	pumpa = 0;

	do
	{
		pumpbreak++;
		PORTB |= (1<<PORTB0);
		for (uint8_t r=0; r < impulse; r++) asm("nop");
		PORTB &= ~(1<<PORTB0);

		TCNT1=0;
		_delay_us(38);
		hv_status = TCNT1;

		if (hv_status) { PORTB &= ~(1<<PORTB0); pumpa=800; } // выходим //7
	}
	while (pumpa++ < 800);

	PORTB &= ~(1<<PORTB0);
}

void count_rad()
{
	volatile unsigned long fon = 0;

	#if (SENSOR_TYPE == SENSOR_SBM21)
		const unsigned int counter_base = 1400; // время датчика / 3 * 10
		// В ОДНОЙ ЯЧЕЙКЕ SBM[] 3(ТРИ) СЕКУНДЫ !!!
		for (unsigned char i=1; i<140; i++)
		{
			fon += sbm[i];

			if (i == 5)
			{
				if(fon > 1800) // фон больше 46800 мкр/ч интервал расчета 15 сек
				{
					fon *= 28;
					if (sbm_count_time != 15) count_validate = 15;
					sbm_count_time = 15;
					i=140; //вылет из цикла, экономим такты
				}
			}
	
			if (i == 28)
			{
				if(fon > 200) //  фон больше 1000 мкр/ч интервал расчета 84 сек
				{
					fon *= 5;
					if (sbm_count_time != 84) count_validate = 84;
					sbm_count_time = 84;
					i = 140; //вылет из цикла, экономим такты
				}
			}

			if (i == 139) 
			{
				if (sbm_count_time != 420) count_validate = 420;
				sbm_count_time = 420;
			}
		}

	#elif (SENSOR_TYPE == SENSOR_SBM21_2)
		const unsigned int counter_base = 1080; // время датчика /2 * 10
		// В ОДНОЙ ЯЧЕЙКЕ SBM[] 2(две) СЕКУНДЫ!!!
		for (uint8_t i=1; i<108; i++)
		{
			fon += sbm[i];

			if (i == 12)
			{
				if(fon > 1800) //фон больше 16 200 мкр/ч интервал расчета 24 сек
				{
					fon *= 9; //
					if (sbm_count_time != 24) count_validate = 24;
					sbm_count_time = 24;
					i = 108; //вылет из цикла, экономим такты
				}
			}

			if (i == 18)
			{
				if(fon > 200) // фон больше 1200 мкр/ч  интервал расчета 36 сек
				{
					fon *= 6;
					if (sbm_count_time != 36) count_validate = 36;
					sbm_count_time = 36;
					i = 108; //вылет из цикла, экономим такты
				}
			}

			if (i == 54)
			{
				if(fon > 100)// фон больше 200 мкр/ч  интервал расчета 108 сек
				{
					fon *= 2;
					if (sbm_count_time != 108) count_validate = 108;
					sbm_count_time = 108;
					i = 108; //вылет из цикла, экономим такты
				}
			}

			if (i == 107)
			{
				if (sbm_count_time != 216) count_validate = 216;
				sbm_count_time = 216;
			}
		}

	#elif (SENSOR_TYPE == SENSOR_SI19)
		const unsigned int counter_base = 320; // время датчика /2 * 10
		// В ОДНОЙ ЯЧЕЙКЕ SBM[] 2(две) СЕКУНДЫ
		for (unsigned char i=1; i<32; i++)
		{
			fon += sbm[i];

			if (i == 2)
			{
				if(fon > 700) // фон больше 14000 мкр/ч интервал расчета 4 сек
				{
					fon *= 20;
					if (sbm_count_time != 4) count_validate = 4;
					sbm_count_time = 4;
					i = 32; //вылет из цикла, экономим такты
				}
			}

			if (i == 8)
			{
				if(fon > 300) // фон больше 1200 мкр/ч интервал расчета 16 сек
				{
					fon *= 4;
					if (sbm_count_time != 16) count_validate = 16;
					sbm_count_time = 16;
					i = 32; //вылет из цикла, экономим такты
				}
			}

			if (i == 16)
			{
				if(fon > 50) // фон больше 100 мкр/ч интервал расчета 32 сек
				{
					fon *= 2;
					if (sbm_count_time != 32) count_validate = 32;
					sbm_count_time = 32;
					i = 32; //вылет из цикла, экономим такты
				}
			}

			if (i == 31)
			{
				if (sbm_count_time != 64) count_validate = 64;
				sbm_count_time = 64;
			}
		}

	#elif (SENSOR_TYPE == SENSOR_SBM20)
		const unsigned int counter_base = 440; // время датчика /2 * 10
		// СБМ-20 датчик без коррекции жёсткости хода (голый) СБМ20 - 44 сек
		// В ОДНОЙ ЯЧЕЙКЕ SBM[] 2(две) СЕКУНДЫ
		for (uint8_t i=1; i<44; i++)
		{
			fon += sbm[i];

			if (i == 6)
			{
				if(fon > 2000)// фон больше 5500 мкР.ч интервал расчета 4 сек
				{
					fon *= 11;
					if (sbm_count_time != 6) count_validate = 6;
					sbm_count_time = 6;
					i = 44; //вылет из цикла, экономим такты
				}
			}

			if (i == 22)
			{
				if(fon > 100) //  фон больше 100 мкР.ч интервал расчета 22 сек
				{
					fon *= 2;
					if (sbm_count_time != 22) count_validate = 22;
					sbm_count_time = 22;
					i = 44; //вылет из цикла, экономим такты
				}
			}

			if (i == 43)
			{
				if (sbm_count_time != 44) count_validate = 44;
				sbm_count_time = 44;
			}
		}

	#elif (SENSOR_TYPE == SENSOR_SBM10)
		const unsigned int counter_base = 1100; // время датчика / 2 * 10
		// СБМ-10 После долгих прикидок и раздумий - датчик без коррекции жёсткости хода (голый) СБМ10 - 220с [78(чувствительность известного нам датчика сбм-20)/12(чувствительность датчика сбм-10)*34(время счёта СБМ20 так все-таки правильнее)]
		// если будем корректировать к примеру свинцовой фольгой чувствительность к частицам низких энергий время будет другим

		// В ОДНОЙ ЯЧЕЙКЕ SBM[] 2(две) СЕКУНДЫ 220
		for (uint8_t i=1; i<110; i++)
		{
			fon += sbm[i];

			if (i == 10)
			{
				if(fon > 18181) // фон больше 200 000 мкр/ч интервал расчета 20 сек
				{
					fon *= 11; //
					if (sbm_count_time != 20) count_validate = 20;
					sbm_count_time = 20;
					i = 110; //вылет из цикла, экономим такты
				}
			}

			if (i == 28)
			{
				if(fon > 20000) // фон больше 80 000 мкр/ч интервал расчета 55 сек
				{
					fon *= 4;
					if (sbm_count_time != 55) count_validate = 55;
					sbm_count_time = 55;
					i = 110; //вылет из цикла, экономим такты
				}
			}

			if (i == 55)
			{
				if(fon > 250) // фон больше 500 мкр/ч интервал расчета 110 сек
				{
					fon *= 2;
					if (sbm_count_time != 110) count_validate = 110;
					sbm_count_time = 110;
					i = 110; //вылет из цикла, экономим такты
				}
			}

			if (i == 109)
			{
				if (sbm_count_time != 220) count_validate = 220;
				sbm_count_time = 220;
			}
		}

	#elif (SENSOR_TYPE == SENSOR_M_SEL)
		if (counter==SENSOR_SBM10)
		{	// SBM10
			for (uint8_t i=1; i<110; i++)
			{
				fon += sbm[i];

				if (i == 10)
				{
					if(fon > 18181) // фон больше 200 000 мкр/ч интервал расчета 20 сек
					{
						fon *= 11; //
						if (sbm_count_time != 20) count_validate = 20;
						sbm_count_time = 20;
						i = 110; //вылет из цикла, экономим такты
					}
				}

				if (i == 28)
				{
					if(fon > 20000) // фон больше 80 000 мкр/ч интервал расчета 55 сек
					{
						fon *= 4;
						if (sbm_count_time != 55) count_validate = 55;
						sbm_count_time = 55;
						i = 110; //вылет из цикла, экономим такты
					}
				}

				if (i == 55)
				{
					if(fon > 250) // фон больше 500 мкр/ч интервал расчета 110 сек
					{
						fon *= 2;
						if (sbm_count_time != 110) count_validate = 110;
						sbm_count_time = 110;
						i = 110; //вылет из цикла, экономим такты
					}
				}

				if (i == 109)
				{
					if (sbm_count_time != 220) count_validate = 220;
					sbm_count_time = 220;
				}
			}
		}
		else
		{	// SBM21
			for (uint8_t i=1; i<140; i++)
			{
				fon += sbm[i];
				if (i == 5)
				{
					if(fon > 1800) // фон больше 46800 мкр/ч интервал расчета 15 сек
					{
						fon *= 28;
						if (sbm_count_time != 15) count_validate = 15;
						sbm_count_time = 15;
						i = 140; //вылет из цикла, экономим такты
					}
				}
	
				if (i == 28)
				{
					if(fon > 200) //  фон больше 1000 мкр/ч интервал расчета 84 сек
					{
						fon *= 5;
						if (sbm_count_time != 84) count_validate = 84;
						sbm_count_time = 84;
						i = 140; //вылет из цикла, экономим такты
					}
				}

				if (i == 139) 
				{
					if (sbm_count_time != 420) count_validate = 420;
					sbm_count_time = 420;
				}
			}
		}
	#else
	#error *** Не определен тип датчика/GM tube type not defined ***
	#endif

	#if (SENSOR_TYPE == SENSOR_SBM21)  // 3 секунды !!!
		if (count_validate && (sbm_count_time - count_validate > 4)) // не 0 значит не обсчитано, значит моргаем прикидочным значением, больше секунд прошло - точнее
		{
			uint8_t approx = (sbm_count_time - count_validate) / 3;
			fon = 0;
			for (uint8_t i=1; i<approx+3; i++)
			{
				fon = fon + sbm[i];
			}
			fon = fon * counter_base / approx / 10; // *на 10 из-за 8битной целой математики, фигово тут сплавающей точкой, лучше даже не связываться, просто "сдвигаем" 10е доли
		}

	#elif (SENSOR_TYPE == SENSOR_SBM20)  // 1 секунда !!!
		if (count_validate && (sbm_count_time - count_validate > 4)) // не 0 значит не обсчитано, значит моргаем прикидочным значением, больше секунд прошло - точнее
		{
			uint8_t approx = (sbm_count_time - count_validate);
			fon = 0;
			for (uint8_t i=1; i<approx+1; i++)
			{
				fon = fon + sbm[i];
			}
			fon = fon * counter_base / approx / 10; // *на 10 из-за 8битной целой математики, фигово тут сплавающей точкой, лучше даже не связываться, просто "сдвигаем" 10е доли
		}

	#elif (SENSOR_TYPE == SENSOR_M_SEL)
		uint8_t t = 1;
		unsigned int counter_base = 0;
		if (counter == SENSOR_SBM10){
			counter_base = 1100;
			t = 2;
        } else {
			counter_base = 1400;
			t = 3;
        }
		if (count_validate && (sbm_count_time - count_validate > 4)) // не 0 значит не обсчитано, значит моргаем прикидочным значением, больше секунд прошло - точнее
		{
			uint8_t approx = (sbm_count_time - count_validate) / t;
			fon = 0;
			for (uint8_t i=1; i<approx+t; i++)
			{
				fon = fon + sbm[i];
			}
			fon = fon * counter_base / approx / 10;	// *на 10 из-за 8битной целой математики, фигово тут сплавающей точкой, лучше даже не связываться, просто "сдвигаем" 10е доли
		}

	#else // 2 секунды
		if (count_validate && (sbm_count_time - count_validate > 4)) // не 0 значит не обсчитано, значит моргаем прикидочным значением, больше секунд прошло - точнее
		{
			uint8_t approx = (sbm_count_time - count_validate) / 2;
			fon = 0;
			for (uint8_t i=1; i<approx+2; i++)
			{
				fon = fon + sbm[i];
			}
			fon = fon * counter_base / approx / 10; // *на 10 из-за 8битной целой математики, фигово тут сплавающей точкой, лучше даже не связываться, просто "сдвигаем" 10е доли
		}
	#endif

	rad = fon;

	#if (ALARM_TYPE == ALARM_DOSE)
		if ((fon_daily / 1000 > alarm_level) && (!alarm_snooze) && (alarm_level))
	#else
		if ((rad > alarm_level) && (!alarm_snooze) && (alarm_level) && (sbm_count_time - count_validate > 5))
	#endif
	{
		if (!awaken) // если спим - ПОДЪЁМ!
		{
			SMCR &=~ (1 << SE); // сны запрещены
			awaken = 61;
			//light = light_level + 1;
		   	pins_on();
		   	EIMSK &=~ (1 << INT0);
		   	PORTB &= ~(1<<PORTB0); //на всякий...
		   	PORTC |= (1<<PORTC0); // питание дисплея вкл
			menu = state_menu_alarm;
			settings = state_settings_hours;
			lcd_init();
			lcd_clear();
			lcd_redraw = 1;
		}

		alarm_beep = 2; beep(BEEP_TONE_KEY1, 254);
		if (scr != state_alarm) lcd_clear();
			scr = state_alarm;
		lcd_redraw = 1;
	}
}
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
void loop()    
{
	if (go_shutdown)
	{
			go_shutdown=0;
			// Гасим всё. То есть совсем всё.
			matrix.end();
			EIMSK=0x01;  // wake button
			TIMSK0=0x00;
			TIMSK1=0x00;
			TIMSK2=0x00;
			PORTB=0x00;
			PORTC=0x00;
			PORTD=0x04;  // подтяжка wake button
			DDRB=0x00;
			DDRC=0x00;
			DDRD=0x00;
			SMCR = (1 << SE)|(0 << SM0)|(1 << SM1)|(0 << SM2); // Разрешаем выключение
			PRR |= (1 << PRADC)|(1 << PRSPI)|(1 << PRTWI)|(1 << PRTIM0); // отрубаем АЦП, СПИ, i2c, таймер писка
			do_shutdown=1;
			asm("sleep");
	}

	if (go_to_bed)	{ go_to_bed=0; pins_off();}

	if (out_of_bed)
	{
		out_of_bed=0;
		pins_on();
		EIMSK &=~ (1 << INT0);
		digitalWrite(PIN_PUMP, LOW);
		//digitalWrite(PIN_OLED_VCC, HIGH);
		/*PORTB &= ~(1<<PORTB0); //на всякий...
		PORTC |= (1<<PORTC0); // питание дисплея вкл*/
		//if (light_level!=2) PORTC |= (1<<PORTC1); // подсветка вкл
		//menu=state_menu_alarm;
		menu=state_menu_alarm;
		scr=state_main;
		displaying_dose=state_main_current;
		key=state_key_none;
		lcd_init();
		lcd_clear();
		lcd_redraw=1;
	}

	if (!do_shutdown)
	{ // POWER OFF		

		if (recount)
		{
			recount=0;
			count_rad();
		}

		if ((awaken)&&(lcd_redraw)) 
		{
			//lcd_redraw=0;
			lcd_draw_screen();
			//if (scr==state_main) lcd_draw_graph();
		}


		if ((batt)&&(awaken)) {batt=0; check_battery();}

		if (awaken) {check_key(); if (key != state_key_none) process_key();}
		if ((piip)&&(awaken)&&(beep_level)) {piip=0; beep(BEEP_TONE_PWR, 65);	}

	} // POWER OFF

	if ((!awaken)||(do_shutdown)) asm("sleep");
}

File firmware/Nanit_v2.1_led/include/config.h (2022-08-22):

#ifndef config_h
#define config_h

// конфигурация пинов
#define PIN_PUMP         8 // PB0

#define PIN_BTN1         2 // PD2
#define PIN_SENSOR       3 // PD3
#define PIN_BTN2         4 // PD4
#define PIN_HV           5 // PD5 

#define PIN_BUZZER1     16 // PC2
#define PIN_BUZZER2     17 // PC3

// тональность звуковых сигналов
#define BEEP_TONE_ALARM 22
#define BEEP_TONE_KEY1  20
#define BEEP_TONE_KEY2  18
#define BEEP_TONE_PWR   14

// тип датчика
#define SENSOR_SBM10     0
#define SENSOR_SBM21     1
#define SENSOR_SBM20	32
#define SENSOR_SI19	    33
#define SENSOR_SBM21_2	34 // 2 счетчика СБМ-21
#define	SENSOR_M_SEL	40 // Выбор через настройки SBM10/SBM21

#ifndef SENSOR_TYPE
#define SENSOR_TYPE SENSOR_SBM21
#endif

// тип батареи
#define BATTERY_LION     0
#define BATTERY_NORMAL   1

#ifndef BATTERY_TYPE
#define BATTERY_TYPE BATTERY_LION
#endif

// тип предупреждения
#define ALARM_DOZE       0
#define ALARM_FON        1

#ifndef ALARM_TYPE
#define ALARM_TYPE ALARM_FON
#endif

// адреса в eeprom для хранения настроек
#define EEPROM_ADDR_BEEP_LEVEL 0
#define EEPROM_ADDR_SLEEP_LEVEL 2
#define EEPROM_ADDR_ALARM_LEVEL 4
#define EEPROM_ADDR_ION 8
#define EEPROM_ADDR_IMPULSE 16
#define EEPROM_ADDR_COUNTER 32
#define EEPROM_ADDR_BRIGHTNESS_LEVEL 128

#endif

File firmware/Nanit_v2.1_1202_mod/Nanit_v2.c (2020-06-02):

/*
 * nanit.c
 *
 * Created: 2014
 * Author: MadOrc
 * Optimization: DooMmen
 * 
 * ВЕРСИЯ 2.1 релиз
 */  

#include "Nanit_v2.h"

//////////////////////
void nlcd_Print_str(uint32_t message, unsigned char number_size, unsigned char leading_zero, unsigned char x, unsigned char y, unsigned char inv);
void Init_LCD();
void PinsOn();
void PinsOff();
void CheckKey();
void Draw_Screen();
void Count_Rad();
void Beep(unsigned char tone, unsigned char duration);
static void Pump();
void CheckBatt();

//////////////////////////////////////////////////////////////////////////
void(* resetMC) (void) = 0; // Reset MC

//////////////////////////////////////////////////////////////////////////
EMPTY_INTERRUPT (ADC_vect)

//////////////////////////////////////////////////////////////////////////
ISR(INT0_vect) // Кнопка1
{
	SMCR &=~ (1 << SE); // сны запрещены
	if (do_shutdown)
	{
		do_shutdown=0;
		resetMC();
	}

	if (sleep_level) awaken=sleep_level+1; else awaken=61;
	if (light_level) light=light_level+1; else light=61;
	scr=0; // Если уснули в меню - проснемся на главном
	out_of_bed=1;
	piip=0;
	Beep(22, 20);
	key=5; // пустая обработка, чтобы при выходе из сна, не реагировал на кнопку
}		

//////////////////////////////////////////////////////////////////////////
ISR(INT1_vect) // импульсы с датчика 0
{
	PORTB &= ~(1<<PORTB0); //на всякий...
	sbm[0]++;
	piip=1;
}

//////////////////////////////////////////////////////////////////////////
ISR(TIMER2_OVF_vect)	// обработчик прерывания по совпадению Т2
{                       
	PORTB &= ~(1<<PORTB0);	//на всякий...

	TCNT2 = 0xE0;			//обновим счетчик

	second++;				// увеличиваем секунды

	if (awaken==1) go_to_bed=1; // СПАТЬ!
	if (light==1) {PORTC &=~ (1<<PORTC1); }// гасим свет
	
	if ((awaken)&&(sleep_level)) awaken--; //обратный отсчёт до сна
	if ((light)&&(light_level)) light--; //обратный отсчёт до вырубания подсветки


	if (count_validate>0) count_validate--;

//	if (sbm_count_time-count_validate > 3) // сброс валидатора, для оперативного пересчета показаний при резкой смене фона, сравним элементы массива импульсов через 1
//	{
//		if ((sbm[1]>sbm[3])&&((sbm[1]-sbm[3])>impulse_threshold)) count_validate=sbm_count_time;
//		if ((sbm[1]<sbm[3])&&((sbm[3]-sbm[1])>impulse_threshold)) count_validate=sbm_count_time;
//	}

	#if (COUNTER_D == SBM21)	// 3!! секунды
		if (!count_flag)	// 0
		{
			div_graph_sbm=1;
			for(unsigned char i=139;i>0;i--) // k - не менее отображаемого графа [48]/[96]!
			{
				sbm[i]=sbm[i-1];
				#ifdef G_2_LINE
					if ((sbm[i]>div_graph_sbm)&&(i<48)) div_graph_sbm=sbm[i]; // Делитель графиков.
				#else
					if ((sbm[i]>div_graph_sbm)&&(i<96)) div_graph_sbm=sbm[i]; // Делитель графиков.
				#endif
			}
			sbm[0]=0;
		}
		if (count_flag<2) count_flag++; else count_flag=0;

	#elif (COUNTER_D == SBM21_2) // 2!! секунды
		if (count_flag)
		{
			div_graph_sbm=1;
			for(unsigned char i=107;i>0;i--) // k - не менее отображаемого графа [48]/[96]!
			{
				sbm[i]=sbm[i-1];
				#ifdef G_2_LINE
					if ((sbm[i]>div_graph_sbm)&&(i<48)) div_graph_sbm=sbm[i]; // Делитель графиков.
				#else
					if ((sbm[i]>div_graph_sbm)&&(i<96)) div_graph_sbm=sbm[i]; // Делитель графиков.
				#endif
			}
			sbm[0]=0;
		}
		if (count_flag) count_flag=0; else count_flag=1;

	#elif (COUNTER_D == SI19) // 2 секунды
		if (count_flag)
		{
			div_graph_sbm=1;
			for(unsigned char i=50;i>0;i--) // k - не менее отображаемого графа [48]!
			{
				sbm[i]=sbm[i-1];
				if ((sbm[i]>div_graph_sbm)&&(i<48)) div_graph_sbm=sbm[i]; // Делитель графиков.
			}
			sbm[0]=0;
		}
		if (count_flag) count_flag=0; else count_flag=1;

	#elif (COUNTER_D == SBM10)   // 2 секунды
		if (count_flag)
		{
			div_graph_sbm=1;
			for(unsigned char i=109;i>0;i--) // k - не менее отображаемого графа [48]/[96]!
			{
				sbm[i]=sbm[i-1];
				#ifdef G_2_LINE
					if ((sbm[i]>div_graph_sbm)&&(i<48)) div_graph_sbm=sbm[i]; // Делитель графиков.
				#else
					if ((sbm[i]>div_graph_sbm)&&(i<96)) div_graph_sbm=sbm[i]; // Делитель графиков.
				#endif
			}
			sbm[0]=0;
		}
		if (count_flag) count_flag=0; else count_flag=1;

	#elif (COUNTER_D == SBM20) // 1!!! секунда
		div_graph_sbm=1;
		for(unsigned char i=50;i>0;i--) // k - не менее отображаемого графа [48]!
		{
			sbm[i]=sbm[i-1];
			if ((sbm[i]>div_graph_sbm)&&(i<48)) div_graph_sbm=sbm[i]; // Делитель графиков.
		}
		sbm[0]=0;

	#elif (COUNTER_D == M_SEL)
		if (counter == SBM10)
		{
			if (count_flag<1) count_flag++; else count_flag=0;
		}
		else
		{
			if (count_flag<2) count_flag++; else count_flag=0;
		}
		if (!count_flag)
		{
			div_graph_sbm=1;
			unsigned char m;
			if (counter == SBM10) m=109;
			else m=139;
			for(unsigned char i=m;i>0;i--) // k - не менее отображаемого графа [48]!
			{
				sbm[i]=sbm[i-1];
				if ((sbm[i]>div_graph_sbm)&&(i<96)) div_graph_sbm=sbm[i]; // Делитель графиков.
			}
		sbm[0]=0;
		}
	#else
	#error *** Не определен тип датчика/GM tube type not defined ***
	#endif

	//if ((rad>radmax)&&(!count_validate)) radmax=rad; // Валидно - если измерено.
    if (rad>radmax) radmax=rad; // Забиваем на валидность
	fonsecond += rad; // 
	fon_daily=(fon_daily+fonsecond)/3600;
	if(second == 60)			// если second = 60, second = 0
	{  // second
		second = 0;
		minute++;				// увеличиваем минуты
		if (alarm_snooze) alarm_snooze--;
		if (!rad) fonerr++;
		if ((fonerr>10)&&(!alarm_snooze)) { nlcd_Clear(); scr=5; alarm_beep=2; fonerr=0;} // Ошибка датчика, нет импульсов 
		batt=1;

		if(minute == 60)		// если minute = 60, minute = 0
		{  // minute
			minute = 0;
			hour++;				// увеличиваем часы

		if(hour == 24)			// если hour = 24, hour = 0
		{ // hour
			hour = 0;
			days++;
			fonall+=fon_daily;
			fonsecond=0;
			fon_daily=0;
			radmax=0;

		} // hour
		} // minute
		} // second

	if (second%2==0) Pump();
	redraw_LCD=1;
	recount=1;
}

//////////////////////////////////////////////////////////////////////////
ISR(TIMER0_COMPA_vect)
{ //sound
	if (blink_status) 
	{
		BEEP_1;
		blink_status=0;
	}
	else
	{
		BEEP_2;
		blink_status=1;
	}

	if (beep_counter++>beep_length)	// 
	{ 
		TIMSK0 &=~ (1 << OCIE0A); 
		BEEP_OFF;
		beep_counter=0; 
		if (alarm_beep==2)	{alarm_beep=0; Beep(20, 254);}
	}
}
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

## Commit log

2020-02-07 initial version
    [nanit.kicad_pcb, nanit.sch]
2020-02-07 Added LED driver for LCD display, gerbers for rev.A
    [nanit.kicad_pcb, nanit.sch]
2020-02-07 Refactored a project structure
    [nanit.kicad_pcb, nanit.sch]
2020-02-08 Added BOM
2020-02-08 latest pcb and schematics
    [nanit.kicad_pcb, nanit.sch]
2020-02-08 Added PCB rev.A renders
2020-02-08 Added PCB renders
2020-06-02 pcb rev.B
    [nanit.kicad_pcb, nanit.sch]
2021-08-21 disabled serial, used SPI for SSD1306
2021-08-23 PCB rev.C (OLED version)
    [nanit.kicad_pcb, nanit.sch]
2021-08-23 missing pcb files
2022-05-01 Added firmware for rev.D board
2022-05-07 Fixed beeps, added battery level mode
    [config.h, main.cpp]
2022-07-25 revD fixes - missing AREF capacitor C7
    [nanit.kicad_pcb, nanit.kicad_sch]
2022-07-29 Fixed Li-Ion discharge level, fixed menu state after awake
    [main.cpp]
